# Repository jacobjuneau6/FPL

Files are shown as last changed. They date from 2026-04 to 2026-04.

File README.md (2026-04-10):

# FPL
FPL is a FPGA based board that runs linux and provides many digital interfaces.
# WHY
I have always wanted to have a benchtop device that can probe I2C,SPI and uart devices all ath the same time. In addition, I have always wanted to mess around with and use an FPGA.
# PCB
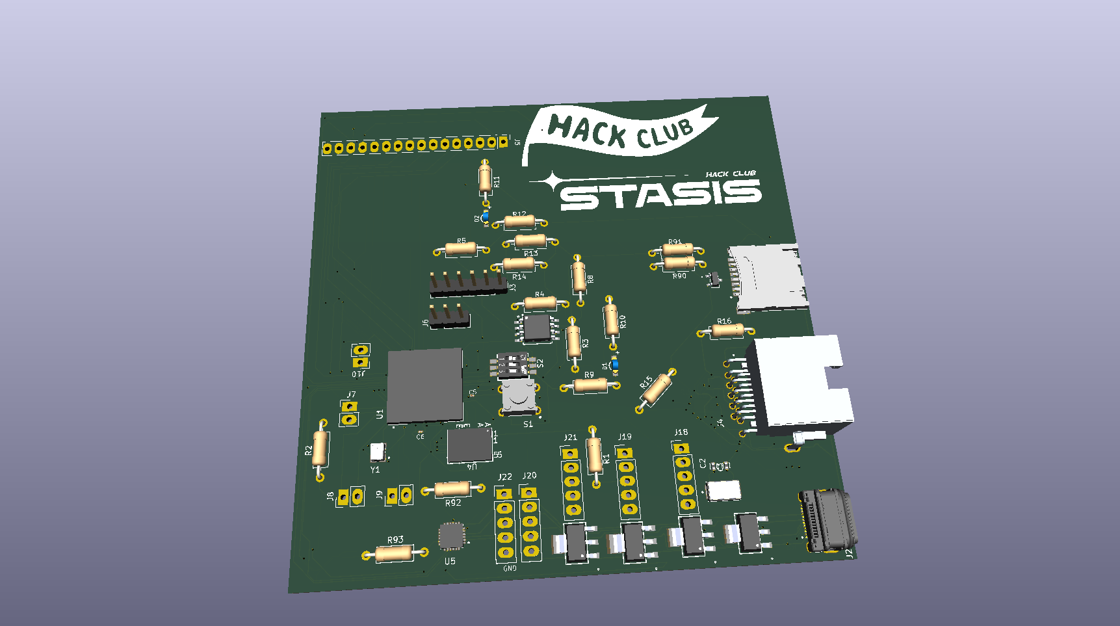
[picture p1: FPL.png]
PCB

# BOM
| Name | Purpose | Quantity | Total Cost (USD) | Link | Distributor |
| --- | --- | --- | --- | --- | --- |
| 50g Solder Paste | To solder the componets to the board | 1 | 7.34 | https://www.aliexpress.com/item/3256809620386958.html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 | Aliexpres |
| FT232H USB -> Bridge | allows programming and debugging the fpga before the core starts | 1 | 7.72 | https://www.aliexpress.com/item/3256810218473690.html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 | Aliexpress |
| M-F Dupont Cable | to connect debugger and peripherals | 1 | 2.27 | https://www.aliexpress.com/item/3256803454873245.html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 | Aliexpress |
| F-F dupont cable | to wire up debugger and peripherals | 1 | 2.06 | https://www.aliexpress.com/item/3256803454873245.html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 | Aliexpress |
| solder paste scraper | to apply the solder paste | 5 | 3.61 | https://www.aliexpress.com/item/3256807243226858.html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 | Aliexpress |
| JLCPCB Stencils | to make assembly easier | 2 | 6.09 |  | JLCPCB |
| JLCPCB PCBs | Holds all components | 5 | 7.00 |  | JLCPCB |
| MicroSD card holder | storage | 1 | 1.57 | https://www.digikey.com/en/products/detail/hirose-electric-co-ltd/DM3CS-SF/2602739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 | Digikey |
| USB-C connector | data transfer | 1 | 2.99 | https://www.digikey.com/en/products/detail/hirose-electric-co-ltd/CX90BW1-24P1/22566049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 | Digikey |
| Ethernet Jack | data transfer | 1 | 4.42 | https://www.digikey.com/en/products/detail/te-connectivity-amp-connectors/2041411-1/7039302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 | Digikey |
| Mosfet | reset the sd card | 1 | 0.28 | https://www.digikey.com/en/products/detail/infineon-technologies/BSS84PH6327XTSA2/5413661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 | Digikey |
| 10K resistors | filtering | 18 | 0.00 |  |  |
| 5.1K resistors | filtering | 2 | 0.20 | https://www.digikey.com/en/products/detail/yageo/RC0402FR-075K1L/726624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 | Digikey |
| Infineon S80KS5123GABHV020 | RAM | 1 | 11.59 | https://www.digikey.com/en/products/detail/infineon-technologies/S80KS5123GABHV020/15965285 | Digikey |
| tactile button | fpga reset | 1 | 0.24 | https://www.digikey.com/en/products/detail/omron-electronics-inc-emc-div/B3F-1000/33150 | Digikey |
| Dip switches | fpga confiuration | 1 | 3.41 | https://www.digikey.com/en/products/detail/w%C3%BCrth-elektronik/416131160803/3174527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 | Digikey |
| FPGA | main chip | 1 | 21.78 | https://www.digikey.com/en/products/detail/lattice-semiconductor-corporation/LFE5U-25F-6BG256C/9553918 | Digikey |
| Ethernet Interface | data transfer | 1 | 1.03 | https://www.digikey.com/en/products/detail/microchip-technology/LAN8720A-CP-TR/3872109 | Digikey |
| 1V2 LDO | power regulation | 1 | 0.39 | https://www.digikey.com/en/products/detail/stmicroelectronics/LD1117S12CTR/1880164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 | Digikey |
| CP2102 | usb>uart | 1 | 4.14 | https://www.digikey.com/en/products/detail/silicon-labs/CP2102N-A02-GQFN24R/9863479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 | Digikey |
| SPI Flash | storage | 1 | 2.31 | https://www.digikey.com/en/products/detail/winbond-electronics/W25Q128JVSIQ-TR/5803944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 | Digikey |
| 25MHZ clock | clock | 1 | 0.99 | https://www.digikey.com/en/products/detail/abracon-llc/ASE-25-000MHZ-L-C-T/1236885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 | Digikey |
| 25MHZ Parrallel clock | ethernet | 1 | 1.02 | https://www.digikey.com/en/products/detail/ecs-inc/ECS-250-18-23A-EN-TR/2213748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 | Digikey |
| 4.7K resistors | filtering | 3 | 0.30 | https://www.digikey.com/en/products/detail/yageo/RC0402JR-074K7L/726477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 | Digikey |
| 0.1uF capacitor | power filtering | 4 | 0.32 | https://www.digikey.com/en/products/detail/murata-electronics/GRM022D80G104ME15L/5027471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 | Digikey |
| 22pF capacitor | power filtering | 2 | 0.16 | https://www.digikey.com/en/products/detail/yageo/CC0402JRNPO9BN220/302752 | Digikey |
| 3V3 LDO | power regulation | 1 | 0.32 | https://www.digikey.com/en/products/detail/stmicroelectronics/LD1117S33CTR/585765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 | Digikey |
| 2V5 LDO | power regulation | 1 | 0.49 | https://www.digikey.com/en/products/detail/stmicroelectronics/LD1117S25CTR/585764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 | Digikey |
| 1V8 LDO | power regulation | 1 | 0.42 | https://www.digikey.com/en/products/detail/stmicroelectronics/LD1117S18TR/1038359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 | Digikey |
| green LED | indication light | 2 | 0.54 | https://www.digikey.com/en/products/detail/w%C3%BCrth-elektronik/155124GS73200A/8557187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 | Digikey |

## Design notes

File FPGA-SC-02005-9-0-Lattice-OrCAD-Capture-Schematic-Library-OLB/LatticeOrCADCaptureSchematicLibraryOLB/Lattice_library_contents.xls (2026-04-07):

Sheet: Revision History
Lattice Semiconductor
Schematic symbol index for OrCAD Capture library: LATTICEPLDS.OLB.
 | Rev No. | Revisions
 |  | 21jul06 1. Added LFXP6-T144, LFXP6-fpBGA256, LFXP20-fpBGA256. 2. Corrected power pins of ECP2-12/22/35/50-fpBGA484.
 |  | 1aug06 Added MachXO_256_csBGA100.
 |  | 9aug06 Added ispMACH4128V/4256V-TQ144
 |  | 31oct06 1. Added LFE2-50-F672 and LFE2M-35-F672. 2. Changed symbol naming conventions to match data sheet conventions.
 |  | 14nov06 Added LCMXO2280-FT324/FTN324
 |  | 10dec06 Added LFE2-6/12/20-F256
 |  | 14dec06 1. Corrected power pins of LFE2-12/22/35/50-F484 2. Added LFE2M-35-F484
 |  | 11jan07 Added LFSC80-FC1704/FCN1704
 |  | 12jan07 Added LFXP15-F484/FN484
 |  | 18jan07 Added LFE2M-20/30-F256
 |  | 24jan07 Added LFE2M-35/50-F672
 |  | 12feb07 1. Added LFE2-6/12-T144/TN144. 2. Added LFE2-12/20-Q208/QN208.
 |  | 23feb07 Added LFXP15/20-F256/FN256.
 |  | 8mar07 Added LFEC2M-70-F900.
 |  | 20mar07 Added LFSC15-F256 and LCMXO256-M100/MN100.
 |  | 21mar07 Added LFE2M-50-F484 and correction to LFSC15-F256.
 |  | 9apr07 Added GAL18V10B.
 |  | 11apr07 Added LFXP6-Q208/QN208.
 |  | 1jun07 1. Added LFXP2-17E-FT256CES. 2. Added LFXP2-17-F484.
 |  | 5jun07 Added LFSC/M25-F900/FN900.
 |  | 15jun07 Added LCMXO2280-T100/TN100
 |  | 12jul07 1. Added LFSCM40-FF1020CES. 2. Added LFXP20-F484/FN484.
 |  | 13jul07 Added LFXP2-17E-Q208/QN208
 |  | 16jul07 Added LFE2-70E-F672/FN672
 |  | 2aug07 Added LFXP2-8E-M132/MN132
 |  | 13aug07 Added LFE2-70E-F900/FN900
 |  | 17sep07 Added ispGAL22V10-J/JN, ispGAL22V10-K/KN
 |  | 19sep07 Added ispGAL22V10A-J, ispGAL22V10A-N
 |  | 26sep07 Added LCMXO640-M132/MN132, LCMXO1200-M132/MN132, LCMXO2280-M132/MN132
 |  | 11oct07 1. Added LFE2-20-F256. 2. LFE2-6/12/20-F256 moved G16 from bank 3 to 2.
 |  | 16oct07 Added LCMXO1200-T144/TN144.
 |  | 23oct07 Added LFXP2-5-M132/MN132.
 |  | 06nov07 1. Updated LFSCM40-FF1020CES to reflect Rev 1.7 of data sheet. 2. Added LFXP2-40E-FPBGA672
 |  | 13nov07 Added LFE2-20E-F672
 |  | 14nov07 Added LFXP2-5E-FT256/FTN256
 |  | 30nov07 Added LC4032Z-M56, LC4064Z-M56
 |  | 13dec07 Added LFE2-35E-F672
 |  | 18dec07 Swapped bank labels 2 and 3. Removed LSCC logo.
 |  | 07jan08 Added LFE2M-70-F1152
 |  | 21jan08 Added LFE2M-100-F1152
 |  | 15feb08 Added LC4384-F256
 |  | 25feb08 1. Corrected PLL FB/IN pins of LFECP6/10/15/20-F484/FN484 2. Added LFE6-F484/FN484 and LFECP6-F484/FN484 based on 3.1 of data sheet
 |  | 12mar08 Moved pin C8 from Bank 1 to Bank 0 LCMXO2280-M132/MN132
 |  | 30Apr08 Added LC4032ZE-TN48, LC4032ZE-MN64, LC4064ZE-TN48, LC4064ZE-MN64, LC4064ZE-TN100, LC4064ZE-MN144, LC4128ZE-TN100, LC4128ZE-MN144, LC4128ZE-TN144, LC4256ZE-TN100, LC4256ZE-MN144, LC4256ZE-TN144 based on April 2008 data sheet
 |  | 12may08 Added LCMXO256-M100/MN100
 |  | 20may08 Updated LFXP2-17E-F484CES using data sheet version 1.4
 |  | 10Jun08 Updated LFXP2-5E-Q208/QN208, LFXP2-8E-Q208/QN208, and LFXP2-8E-F256/FT256.
 |  | 16Jun08 Updated LFXP3-T100/TN100, LFXP3-T144/TN144, LFXP6-T144/TN144, LFXP6-F256/FN256, LFXP10-F256/FN256, LFXP10-F388/FN388, LFXP20-F484/FN484, LCMXO256-T100/TN100
 |  | 10Jul08 Added LFXP2-30E-FT256/FTN256 and LFXP2-40E-F484/FN484
 |  | 8Sep08 Added LFE2M-100E-F900C
 |  | 6Oct08 Added LFE2M-50E-F900
 |  | 20Oct08 1. Added MachXO: LCMXO640-T100/TN100, LCMXO1200-TN100/TN100, LCMXO2280-T144/TN144, and LCMXO2280-FT256/FTN256. 2. Added ispCLOCK: ispPAC-CLK5304S-01T48/TN48, ispPAC-CLK5308S-01T48/TN48, ispPAC-CLK5312S-01T48/TN48, ispPAC-CLK5316S-01T64/TN64, and ispPAC-CLK5320S-01T64/TN64. 3. Added Power Manager: ispPAC-POWR1014-01T48/TN48, ispPAC-POWR1014A-01T48/TN48, ispPAC-POWR1208-01T44/TN44, ispPAC-POWR1208P1-01T44/TN44, ispPAC-POWR1220AT8-01T100/TN100, ispPAC-POWR604-01T44/TN44, ispPAC-POWR604/1208-01T44/TN44, ispPAC-POWR607-01N32/NN32, ispPAC-POWR6AT6-01N32/NN32.
 |  | 23Feb09 1. Added ispPAC-CLK5406D-01-SN48 and ispPAC-CLK5410D-01-SN64
 |  | 30Feb09 1. Added LFE3-70-FN484
 |  | 23Mar09 1. Added LFE3-35-FN484
 |  | 25Mar09 1. Added LFE3-17E-FN256CES, LFE3-17E-FN484CES, LFE3-35E-FN256CES, LFE3-35E-FN672CES, LFE3-70E-FN672CES, LFE3-70E-FN1156CES, LFE3-95E-FN484CES, LFE3-95E-FN672CES, LFE3-95E-FN1156CES, LFE3-150E-FN672CES, LFE3-150E-FN1156CES, LX64-F100C, LX128-F208C, LX256-F484C
 |  | 2010-05-24
 |  | 1. Added LFE-17EA/35EA-FN256
 |  | 2010-06-04
 |  | 1. Deleted LFE-35E-FN256 -- Use EA part instead
 |  | 2010-06-17
 |  | 1. Deleted LFE3-17E-FN256CES -- Use EA part instead
 |  | 2010-07-14
 |  | 1. Corrected GND pins for LC4032ZE-MN64 and LC4064ZE-MN64
 |  | 2010-08-07
 |  | 1. Marked pins AH24,25,26 and 27 as NC for the LFSC15-F900
 |  | 2010-08-07
 |  | 1. Renamed ECP3 35,70 and 95 from E to EA. Same pinouts
 |  | 2011-01-10
 |  | 1. Added LFE3-150EA-FN1156C, this is the symbol used on the ECP3 IO Procotol evaluation board. It has separated bank symbols with indication for DQ groups, DQS, and true LVDS outputs.
 |  | 2011-01-13
 |  | 1. Added MachXO2 LCMX02-1200-TG100 and MG132, LCMXO2-2000-FTG256. 2. Platform Manager LPTM10-1247-TG128 and LPTM10-12107-FTG208.
 |  | 2011-07-12
 |  | 1. LCMXO2-1200-TG100 Changed VCCP pin 89 to NC
 |  | 2. LCMXO2-1200-MG132 Changed VCCP pin C7 to NC
 |  | 3. LCMXO2-1200-TG144 Changed VCCP pin 129 to NC
 |  | 4. LCMXO2-2000-FTG256 Changed VCCP pin A2 to NC
 |  | 2011-07-22
 |  | LFSC15-F900 1) Added missing NC pins
 |  | 2) Consolidated VCC12 pins in one place
 |  | 3) Added secondary functions
 |  | 2011-08-18
 |  | 1. Added MachXO2, LCMXO2-1200-UWG25
 |  | 2. Corrected VCCIO pin type from Bidirectional to Power
 |  | 2011-08-24
 |  | 1. Added MachXO2, LCMXO2-2000/4000/7000-FG484
 |  | 2011-09-08
 |  | Moved pins 50 and 75 on XO2-100 to correspond to actual part
 |  | 2011-09-09
 |  | Corrected duplicate pin numbers on MachXO2, LCMXO2-2000/4000/7000-FG484
 |  | 2011-09-12
 |  | Added MachLCMXO2-2000/4000/7000-TG144
 |  | 2011-11-16
 |  | Corrected mis-numbered NC pin on MachXO2, LCMXO2-2000/4000/7000-FG484
 |  | 2011-12-06
 |  | Added MachLCMXO2-256/640/1200/2000-T100
 |  | 2011-12-13
 |  | Cleaned up LFE3-70EA-FN1156CES
 |  | 2012-02-09
 |  | Added MachLCMXO2-1200/2000/4000/7000-FTG256
 |  | 2012-02-16
 |  | Added LFE3-17EA-MG328
 |  | 2012-02-21
 |  | Corrected missing VCCJ pin on LFE2M-50-484
 |  | 2012-02-22
 |  | Added LCMXO2-256-UMG64
 |  | 2012-04-02
 |  | Added LCMXO2-2000-BG256
 |  | 2012-04-18
 |  | Corrected ECP3 names: E to EA and removed CES designation
 |  | 2012-04-25
 |  | Added LCMXO2-256-SG32
 |  | 2012-05-30
 |  | Added LFXP2-40E/30E-FPGA672C
 |  | 2012-06-05
 |  | Renamed LFE3-95/150EA-FN1156, added notes
 |  | 2012-06-05
 |  | Added LCMXO2-640U-TG144
 |  | 2012-06-12
 |  | Corrected labeling of DQ pins on LCMXO2-640U-TG144
 |  | 2012-08-20
 |  | Added LC4512-F256 and LCMXO2-4000-BG332
 |  | 2012-08-21
 |  | Renamed LFE3-95/150EA-FN1156, at LBN
 |  | 2012-09-03
 |  | LFE3-35EA-FN484; Corrected pin type for VCC,VCCAUX, VCCPLL & VCCA from Passive to Power.
 |  | 2012-09-17
 |  | Added LCMXO2-256/640/1200/2000-TG100,
 |  | Added LCMXO2-256/640/1200/2000/4000-MG132
 |  | Renamed pin names for LCMXO2-1200-UWG25
 |  | 2012-09-21
 |  | Added LCMXO2-2K/4K/7K-BG256,
 |  | Added "7000-BG332" device, and changed the symbol name from "LCMXO2-4000-BG332" to :LCMXO2-4000/7000-BG332"
 |  | 2013-01-28
 |  | Corrected LCMXO2-1200-UWG25
 |  | 2013-02-08
 |  | LFE3-95/150EA-FN1156 added CSSPIN ( dual function pin); LFE3-70/95/150EA-FN1156 moved K8/K9 to bank7. LFE3-35EA-FN484 added secondary functions.
 |  | 12-Feb-13 Added MachXO2-4K-184CsBGA Package
 | rev02.0 | 19-April-2013 Added iCE40 device symbols
 |  | iCE40LP384-CM36A
 |  | iCE40LP384-CM49
 |  | iCE40LP384-CM81
 |  | iCE40LP384-QN32
 |  | iCE40LP1K-CB81
 |  | iCE40LP1K-QN84
 |  | iCE40LP1K-CM81
 |  | iCE40LP1K-CM121
 |  | iCE40LP1K-CM36
 |  | iCE40LP1K-CB121
 |  | iCE40LP1K-CM49
 |  | iCE40LP4K-CM81
 |  | iCE40LP4K-CM121
 |  | iCE40LP4K-CM225
 |  | iCE40LP8K-CM81
 |  | iCE40LP8K-CM121
 |  | iCE40LP8K-CM225
 |  | iCE40HX1K-TQ144
 |  | iCE40HX1K-CB132
 |  | iCE40HX1K-VQ100
 |  | iCE40HX4K-CB132
 |  | iCE40HX4K-TQ144
 |  | iCE40HX8K-CB132
 |  | iCE40HX8K-CM225
 |  | iCE40HX8K-CT256
 | rev02.1 | 09-Aug-13 iCE40-LP1K-CM49 updated VPP_FAST pin
 | rev02.2 | 23-Sept-13 iCE40-LM1K-SWG25 added symbol
 | rev02.3 | 21-Oct-13 iCE40-LM1K-SWG25 updated symbol iCE40-LM2K-SWG25 / CE40-LM4K-SWG25 added symbol iCE40-LM1K-CM36 / iCE40-LM2K-CM36 /iCE40-LM4K-CM36 added symbol iCE40-LM1K-CM49 / iCE40-LM2K-CM49 /iCE40-LM4K-CM49 added symbol
 | rev3.0 | Added Internal Symbols
 | rev3.1 | 14th feb Added XO3 symbols [1]LCMXO3L-2100-UWG49 [2]LCMXO3L-1K/2K/4K/7K-BG256
 | rev3.2 | Removed internal Symbols
 | rev3.3 | Updated LCMXO3L-2100-UWG49 with Dual functions
 | rev3.4 | Addedd LCMXO2-200-UWG49
 | rev3.5 | Added ECP5 symbols
 | rev3.6 | Added ECP5 symbols (csBGA285)
 | rev3.7 | Updated ECP5 symbols
 | rev3.8 | Added LCMXO3L-6900-BG400
 | rev3.9 | Added LCMXO3L-4300-UWG81
 | rev3.10 | Added LCMXO3L-2100/4300/6900-BG324 Renamed LCMXO3L-4300/6900 BG400 Added LCMXO3L- 640/1300 MG121 Added LCMXO3L-6900 MG324 Added LCMXO3L-2100/4300-MG324 Added LCMXO3L- 2100 MG121 Added LCMXO3L-1300/2100-MG256 Added LCMXO3L-1300-UWG36 Added LCMXO3L- 4300 MG121
 | rev4.0 | Added iCE5LP-1K-SWG36 / 2K SWG 36 - / 4K SWG36 Added iCE5LP-1K-UWG20 / 2K UWG20 / 4K UWG20
 | rev4.1 | Updated LFE5UM-85-BG381 Added LASC10-SG48 Added LPTM21
 | rev4.2 | Updated LFE5U-25F-MG285 ; LFE5UM-25F-MG285
 | rev4.3 | Updated LCMXO3L-1300-MG121 Updated LCMXO3L-1300-MG256 Updated LCMXO3L-2100-MG121 Updated LCMXO3L-2100-MG256 Updated LCMXO3L-2100-MG324 Updated LCMXO3L-4300-MG121 Updated LCMXO3L-4300-MG256 Updated LCMXO3L-4300-MG324 Updated LCMXO3L-640-MG121 Updated LCMXO3L-6900-MG256 Updated LCMXO3L-6900-MG324 Updated LPTM21 symbol
 | rev4.4 | Added iCE40UL1K-CM36A and iCEUL-1K SWG16
 | rev4.5 | Added iCE5LP-1K-CM36 and iCE5LP-1K-SG48 Added iCE5LP-2K-CM36 and iCE5LP-2K-SG48 Added iCE5LP-4K-CM36 and iCE5LP-4K-SG48
 | rev4.6 | Updated LFE5U-25F-MG285
 | rev4.7 | Added iCE40UP5K-WLCSP30 & iCE40UP5K- SG48
 | rev4.8 | Updated LCMXO3L-1300-UWG36
 | rev4.9 | Added LFE5G-25F-BG381 LFE5G-25F-MG285 LFE5G-45F-BG381 LFE5G-45F-BG554 LFE5G-45F-MG285 LFE5G-85F-BG381 LFE5G-85F-BG554 LFE5G-85F-BG756 LFE5G-85F-MG285
 | rev4.10 | Added LIF-MD6000 CSFBGA81 LIF-MD6000 WLCSP36
 | rev5.1 | Added iCE40UP3K-WLCSP30 & iCE40UP5K- FWG49
 | rev5.2 | Updated Ice40up5k-WLCSP30 (Swapped C1 & D1) Added LIFMD6000-CSFBGA64 & LIFMD6000-CSFBGA80
 | rev5.3 | Updated LFE5UM-25F-MG285 BANK3 Pin Numbers
 | rev5.3 | Updated LFE5UM/5G-85F-MG285 SERDES Pin Numbers Grouped LIFMD6000-Ctfbga80
 | rev5.4 | Updated ice40up3k/5k RGB Pin swaps. Added SII1866CZU
 | rev5.5 | Updated ice40up3k-WLCSP30(Swapped C1 & D1)
 | rev5.6 | Updated LIFMD6000-CSFBGA64. Swapped H3&H4, G7&G8, A6&B6
 | rev5.7 | Added -LCMXO2-256/1200-SG32 -LCMXO2-4000-QFN84 -LCMXO2-256/640-QFN48 -LCMXO3L/LF -9400-MG256 -LCMXO3L/LF-9400-BG256 -LCMXO3L/LF-9400-BG400 -LCMXO3L/LF-9400-BG484
 | rev5.8 | Added LCMXO3H-40E-6FN672I
 | rev5.9 | Removed internal names on all the ECP5 Symbols
 | rev6.0 | Updated All LIFMD Package VCCAUX Pin name and Modifed 80 Pin package VSS to GND. Updated C4 & D5 Swap on 64 Pin package.
 | rev6.1 | Nov-2018 Added -LFE5U-12F-BG256 -LFE5U-25F-BG256 Corrected Ultra Family symbols, changed pin "*SPI_CSN" to "*SPI_SS"
 | rev6.3 | Feb-2019 Broke old LCMXO3L-2100/4300/6900-BG324 symbol into 2 parts: - LCMXO3L-2100/4300-BG324 (no changes) - LCMXO3L-6900-BG324 (updated pin names, no change to pin numbers)
 | rev6.4 | Sept-2019 Added -LFE5UM-45F-BG256 -LIFMDF6000-ucFBGA64
 | rev6.5 | March 2020 - added LPTM21L-CAG100
 | rev6.6 | April 2020 Added -LIFCL-40-BG400 -LIFCL-40-MG289 -LIFCL-40-SG72
 | rev6.7 | June 2020 Added -LIFCL-40-MG121 -LIFCL-40-BG256 -LFD2NX-40-BG256 -Pin updates on LIFCL-40-BG400: Minor name update on ball D15, fixed ball swap error on R16/T16 -Pin update on LIFCL-40-SG72: Minor name update on pin 53
 | rev6.8 | July 2020 -Pin update on LIFCL-40-400: Fixed swapped pin error on PT84A and PT84B
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

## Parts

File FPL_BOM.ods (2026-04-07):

Name | Purpose | Quantity | Total Cost (USD) | Link | Distributor
0.1uF capacitor | power smoothing | 23 | 0.07 | https://www.digikey.com/en/products/detail/murata-electronics/GRM022D80G104ME15L/5027471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 | Digikey
3.3V LDO | Power regulation | 1 | 0.32 | https://www.digikey.com/en/products/detail/stmicroelectronics/LD1117S33CTR/585765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 | Digikey
2.5V LDO | Power regulation | 1 | 0.49 | https://www.digikey.com/en/products/detail/stmicroelectronics/LD1117S25CTR/585764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 | Digikey
Green LED | Indicator Light | 2 | 0.54 | https://www.digikey.com/en/products/detail/w%C3%BCrth-elektronik/155124GS73200A/8557187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 | Digikey
Lattice ECP5 FPGA | Main MCU | 1 | 19.55 | https://www.mouser.com/ProductDetail/Lattice/LFE5U-25F-6TG144C?qs=TuK3vfAjtkUJ2XBiIF%2F%2FCA%3D%3D | Mouser
MicroSD card Slot | Hold a MicroSD card for data | 1 | 1.57 | https://www.digikey.com/en/products/detail/hirose-electric-co-ltd/DM3CS-SF/2602739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 | Digikey
USB-C connector | Provides power and data | 1 | 2.99 | https://www.digikey.com/en/products/detail/hirose-electric-co-ltd/CX90BW1-24P1/22566049 | Digikey
P-Channel Mosfet | Resets MicroSD card | 1 | 0.28 | https://www.digikey.com/en/products/detail/infineon-technologies/BSS84PH6327XTSA2/5413661 | Digikey
10K resistors | Voltage smoothing | 9 | 0
5.1K resistors | Voltage smoothing | 2 | 0.2 | https://www.digikey.com/en/products/detail/yageo/RC0402FR-075K1L/726624 | Digikey
4.7K resistors | Voltage smoothing | 4 | 0.4 | https://www.digikey.com/en/products/detail/yageo/RC0402JR-074K7L/726477 | Digikey
47 OHM resistors | Logic Filtering | 78 | 4.06 | https://www.digikey.com/en/products/detail/rohm-semiconductor/KTR10EZPJ470/1763409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 | Digikey
Tactile Switch | Reset Button | 1 | 0.24 | https://www.digikey.com/en/products/detail/omron-electronics-inc-emc-div/B3F-1000/33150 | Digikey
3 Position DIP switch | FPGA State Control | 1 | 3.41 | https://www.digikey.com/en/products/detail/w%C3%BCrth-elektronik/416131160803/3174527 | Digikey
32MB SDRAM | RAM for RISCV CPU core | 2 | 10.38 | https://www.digikey.com/en/products/detail/winbond-electronics/W9825G6KH-6/5001919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 | Digikey
1.2V LDO | Power regulation | 1 | 0.39 | https://www.digikey.com/en/products/detail/stmicroelectronics/LD1117S12CTR/1880164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 | Digikey
16MB SPI flash | FPGA STATE data and RISC-V microcode | 1 | 2.31 | https://www.digikey.com/en/products/detail/winbond-electronics/W25Q128JVSIQ-TR/5803944 | Digikey
CP2102 USB>UART | provides uart over usb from FPGA | 1 | 4.14 | https://www.digikey.com/en/products/detail/silicon-labs/CP2102N-A02-GQFN24R/9863479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 | Digikey
25MHZ clock | provides a base clock for the FPGA | 1 | 0.99 | https://www.digikey.com/en/products/detail/abracon-llc/ASE-25-000MHZ-L-C-T/1236885 | Digikey

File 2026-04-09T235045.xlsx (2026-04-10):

Digi-Key: Shopping Cart
Index | Quantity | Part Number | Manufacturer Part Number | Description | Customer Reference | Available | Backorder | Unit Price | Extended Price USD
1 | 1 | BSS84PH6327XTSA2CT-ND | BSS84PH6327XTSA2 | MOSFET P-CH 60V 170MA SOT23-3 |  | 1 | 0 | 0.26 | 0.26
2 | 1 | A135635CT-ND | 2041411-1 | RJ45 W/ LED, TAB UP, OFFSET, DIP |  | 1 | 0 | 4.42 | 4.42
3 | 1 | 26-CX90BW1-24P1CT-ND | CX90BW1-24P1 | RECEPTACLE, 24POS., USB TYPE-C C |  | 1 | 0 | 2.99 | 2.99
4 | 1 | HR1972CT-ND | DM3CS-SF | CONN MICRO SD CARD R/A SMD |  | 1 | 0 | 1.57 | 1.57
5 | 2 | 311-5.10KLRCT-ND | RC0402FR-075K1L | RES 5.1K OHM 1% 1/16W 0402 |  | 2 | 0 | 0.1 | 0.20
6 | 1 | 448-S80KS5123GABHV020-ND | S80KS5123GABHV020 | IC PSRAM 512MBIT SPI/OCTL 24FBGA |  | 1 | 0 | 11.59 | 11.59
7 | 1 | SW400-ND | B3F-1000 | SWITCH TACTILE SPST-NO 0.05A 24V |  | 1 | 0 | 0.24 | 0.24
8 | 1 | 732-416131160803CT-ND | 416131160803 | SWITCH SLIDE DIP SPST 0.025A 24V |  | 1 | 0 | 3.41 | 3.41
9 | 1 | 220-2205-ND | LFE5U-25F-6BG256C | IC FPGA 197 I/O 256CABGA |  | 1 | 0 | 21.78 | 21.78
10 | 1 | LAN8720A-CP-CT-ND | LAN8720A-CP-TR | IC TRANSCEIVER FULL 2/2 24QFN |  | 1 | 0 | 1.03 | 1.03
11 | 1 | 497-6974-1-ND | LD1117S12CTR | IC REG LINEAR 1.2V 800MA SOT-223 |  | 1 | 0 | 0.39 | 0.39
12 | 1 | 336-5888-1-ND | CP2102N-A02-GQFN24R | IC USB TO UART BRIDGE QFN24 |  | 1 | 0 | 4.14 | 4.14
13 | 1 | W25Q128JVSIQ-ND | W25Q128JVSIQ | IC FLASH 128MBIT SPI/QUAD 8SOIC |  | 1 | 0 | 2.24 | 2.24
14 | 1 | 535-ASE-25.000MHZ-L-C-TCT-ND | ASE-25.000MHZ-L-C-T | XTAL OSC XO 25.0000MHZ CMOS SMD |  | 1 | 0 | 0.99 | 0.99
15 | 1 | XC1671CT-ND | ECS-250-18-23A-EN-TR | CRYSTAL 25.0000MHZ 18PF SMD |  | 1 | 0 | 1.02 | 1.02
16 | 3 | 311-4.7KJRCT-ND | RC0402JR-074K7L | RES 4.7K OHM 5% 1/16W 0402 |  | 3 | 0 | 0.1 | 0.30
17 | 1 | 497-1241-1-ND | LD1117S33CTR | IC REG LINEAR 3.3V 800MA SOT-223 |  | 1 | 0 | 0.32 | 0.32
18 | 10 | 311-1018-1-ND | CC0402JRNPO9BN220 | CAP CER 22PF 50V C0G/NPO 0402 |  | 10 | 0 | 0.003 | 0.03
19 | 1 | 497-1240-1-ND | LD1117S25CTR | IC REG LINEAR 2.5V 800MA SOT-223 |  | 1 | 0 | 0.49 | 0.49
20 | 1 | 497-7308-1-ND | LD1117S18TR | IC REG LINEAR 1.8V 800MA SOT-223 |  | 1 | 0 | 0.42 | 0.42
21 | 2 | 732-12022-1-ND | 155124GS73200A | LED GREEN CLEAR 1206 SMD R/A |  | 2 | 0 | 0.27 | 0.54

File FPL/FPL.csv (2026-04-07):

Reference | Qty | Value | DigiKey_Part_Number | Mouser Part Number
C1,C4,C5,C6 | 4 | GRM022D80G104ME15L | 490-10386-1-ND
C2,C3 | 2 | CC0402JRNPO9BN220 | 311-1018-1-ND
CR1 | 1 | LD1117S33CTR | LD1117S33CTR
CR2 | 1 | LD1117S25CTR | LD1117S25CTR
CR3 | 1 | LD1117S18TR
D1,D2 | 2 | WL-SMSW_1204_A | 732-12022-1-ND
J1 | 1 | DM3CS-SF | HR1972CT-ND
J2 | 1 | CX90BW1-24P1 | 26-CX90BW1-24P1CT-ND
J3 | 1 | PINHD_1x6_Male
J4 | 1 | 2041411-1 | A135635CT-ND
J5,J6 | 2 | PINHD_1x16_Male
J7,J8,J9,J10,J11,J12,J13,J14,J15,J16,J17 | 11 | PINHD_1x2_Male
J18,J19,J20,J21,J22 | 5 | PINHD_1x5_Male
Q1 | 1 | BSS84PH6327XTSA2 | BSS84PH6327XTSA2CT-ND
R1,R2,R3,R4,R5,R8,R9,R10,R11,R12,R13,R14,R15,R16,R90,R91,R92,R93 | 18 | 10k | N/A
R6,R7 | 2 | RC0402FR-075K1L | 311-5.10KLRCT-ND
R87,R88,R89 | 3 | RC0402JR-074K7L | 311-4.7KJRCT-ND
S1 | 1 | B3F-1000 | SW400-ND
S2 | 1 | 416131160803 | 732-416131160803CT-ND
U1 | 1 | LFE5U-25F-6BG256C | 220-2205-ND
U2 | 1 | LAN8720A-CP-TR
U3 | 1 | LD1117S12CTR | LD1117S12CTR
U5 | 1 | CP2102N-A02-GQFN24R | 336-5888-1-ND
U6 | 1 | W959D6NFKX4I
U7 | 1 | W25Q128JVSIQ TR | 256-W25Q128JVSIQTRCT-ND
Y1 | 1 | ASE-25.000MHZ-LC-T | 535-ASE-25.000MHZ-L-C-TCT-ND
Y2 | 1 | ECS-250-18-23A-EN-TR | XC1671CT-ND

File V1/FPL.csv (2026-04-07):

Reference | Qty | Value | DigiKey_Part_Number | Mouser Part Number
C1,C2,C3,C4,C5,C6,C7,C8,C9,C10,C11,C12,C13,C14,C15,C16,C17,C18,C19,C20,C21,C22,C23 | 23 | GRM022D80G104ME15L | 490-10386-1-ND
CR1 | 1 | LD1117S33CTR | LD1117S33CTR
CR2 | 1 | LD1117S25CTR | LD1117S25CTR
D1,D2 | 2 | WL-SMSW_1204_A | 732-12022-1-ND
IC1 | 1 | LFE5U-25F-6TG144C |  | 842-LFE5U25F6TG144C
J1 | 1 | DM3CS-SF | HR1972CT-ND
J2 | 1 | CX90BW1-24P1 | 26-CX90BW1-24P1CT-ND
Q1 | 1 | BSS84PH6327XTSA2 | BSS84PH6327XTSA2CT-ND
R1,R2,R3,R4,R5,R90,R91,R92,R93 | 9 | 10k | N/A
R6,R7 | 2 | RC0402FR-075K1L | 311-5.10KLRCT-ND
R8,R87,R88,R89 | 4 | RC0402JR-074K7L | 311-4.7KJRCT-ND
R9,R10,R11,R12,R13,R14,R15,R16,R17,R18,R19,R20,R21,R22,R23,R24,R25,R26,R27,R28,R29,R30,R31,R32,R33,R34,R35,R36,R37,R38,R39,R40,R41,R42,R43,R44,R45,R46,R47,R48,R49,R50,R51,R52,R53,R54,R55,R56,R57,R58,R59,R60,R61,R62,R63,R64,R65,R66,R67,R68,R69,R70,R71,R72,R73,R74,R75,R76,R77,R78,R79,R80,R81,R82,R83,R84,R85,R86 | 78 | KTR10EZPJ470 | RHM47BCT-ND
S1 | 1 | B3F-1000 | SW400-ND
S2 | 1 | 416131160803 | 732-416131160803CT-ND
U1,U2 | 2 | W9825G6KH-6 | W9825G6KH-6-ND
U3 | 1 | LD1117S12CTR | LD1117S12CTR
U4 | 1 | W25Q128JVSIQ TR | 256-W25Q128JVSIQTRCT-ND
U5 | 1 | CP2102N-A02-GQFN24R | 336-5888-1-ND
Y1 | 1 | ASE-25.000MHZ-LC-T | 535-ASE-25.000MHZ-L-C-TCT-ND

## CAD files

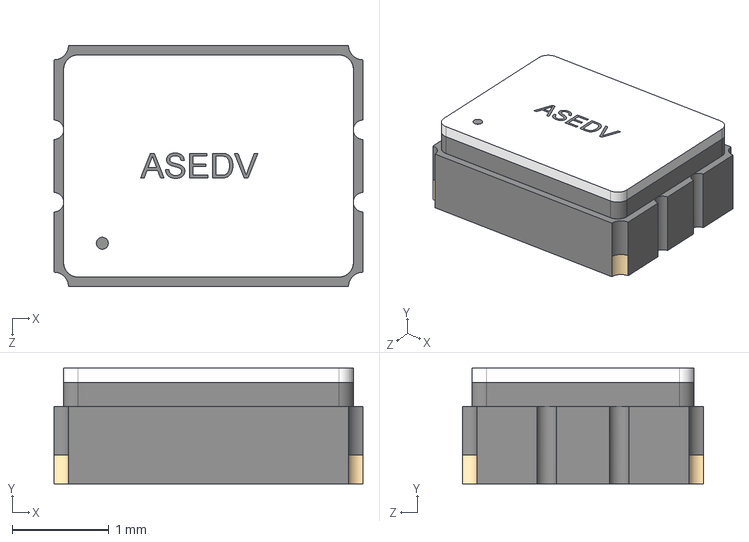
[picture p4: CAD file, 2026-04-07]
FPL/symbols/ASE-25.000MHZ-LC-T/ASE-25.000MHZ-LC-T.step
3.20 x 1.20 x 2.50 mm

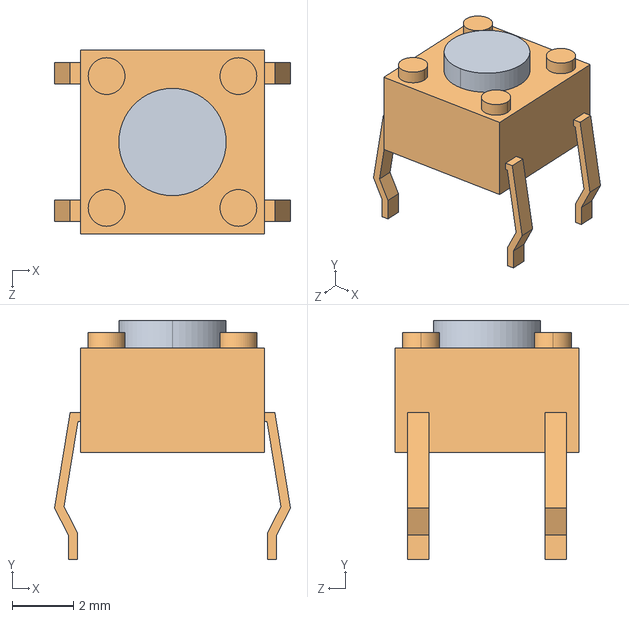
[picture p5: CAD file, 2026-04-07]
FPL/symbols/B3F-1000/B3F-1000.step
7.70 x 7.80 x 6.00 mm
B3F_1000_BUTTON
B3F_1000_BASE

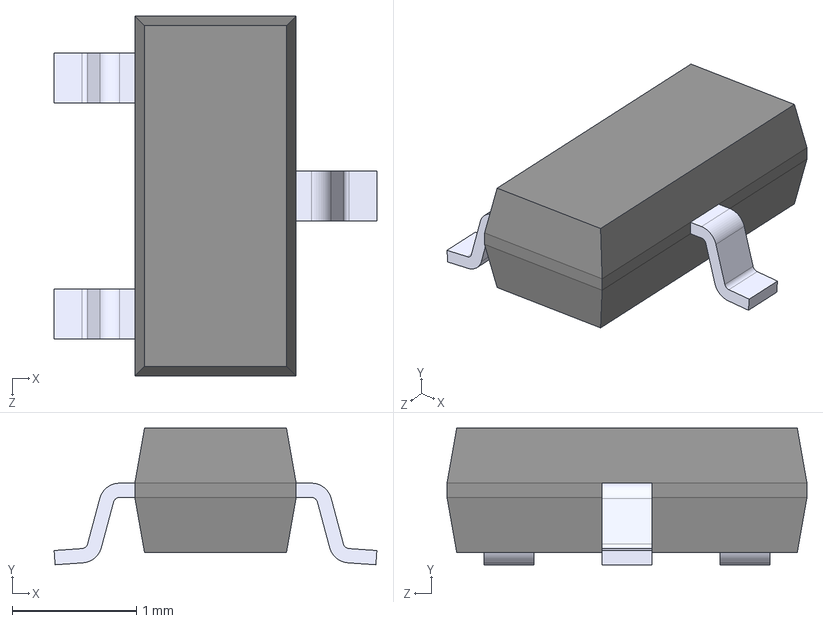
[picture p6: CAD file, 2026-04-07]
FPL/symbols/BSS84PH6327XTSA2.STEP
2.60 x 1.10 x 2.90 mm

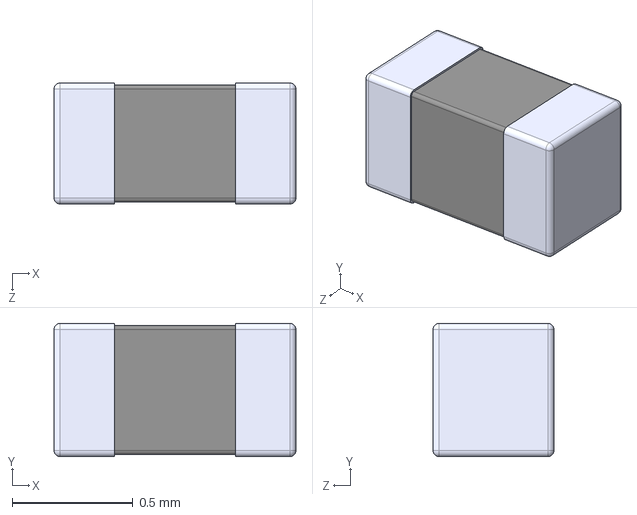
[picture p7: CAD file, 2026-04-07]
FPL/symbols/CC0402JRNPO9BN220/CC0402JRNPO9BN220.step
1.00 x 0.55 x 0.5 mm

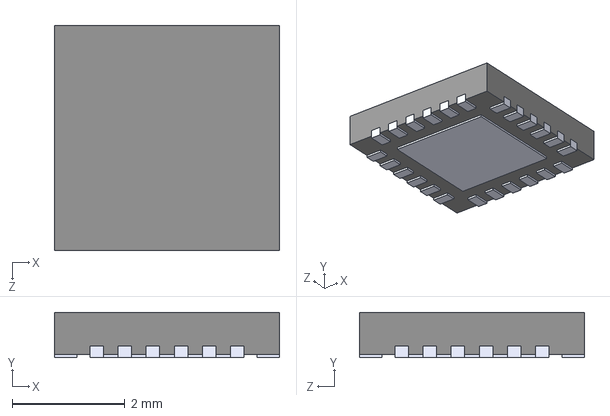
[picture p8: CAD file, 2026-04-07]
FPL/symbols/CP2102N-A02-GQFN24R/CP2102N-A02-GQFN24R.step
4.00 x 0.8 x 4.00 mm

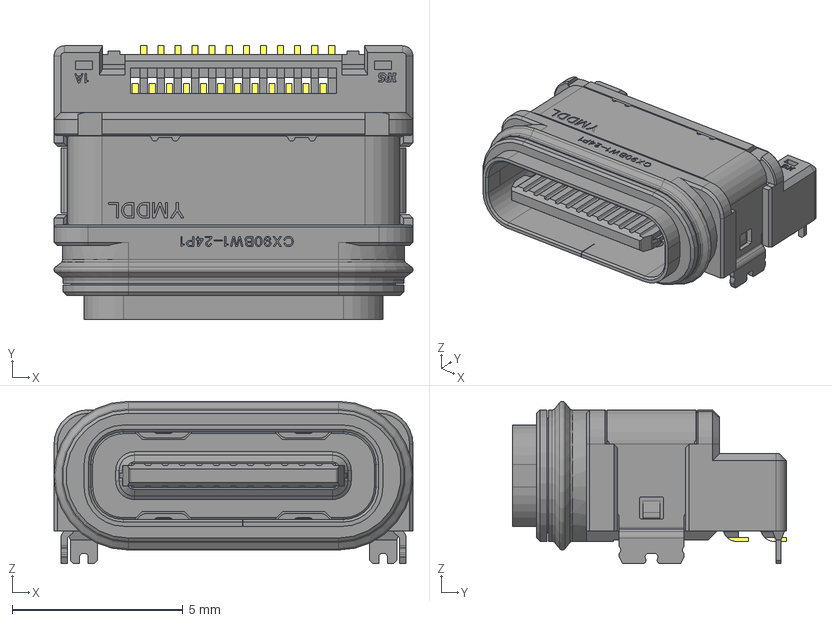
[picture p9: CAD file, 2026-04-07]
FPL/symbols/CX90BW1-24P1/CX90BW1-24P1.step
10.5 x 8.00 x 4.75 mm

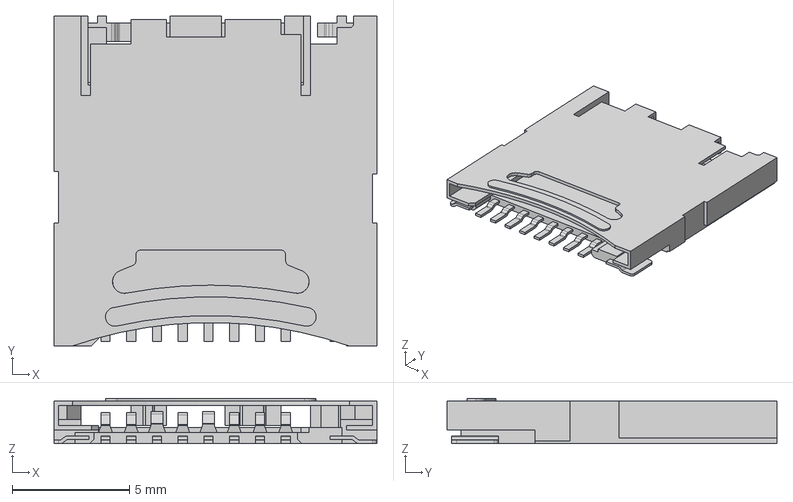
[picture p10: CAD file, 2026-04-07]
FPL/symbols/DM3CS-SF/DM3CS-SF.step
13.8 x 14.1 x 1.93 mm

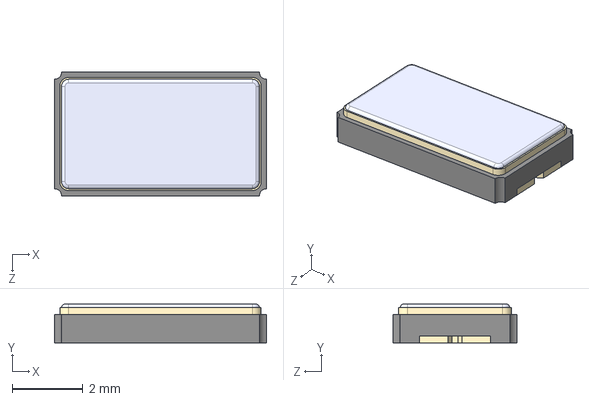
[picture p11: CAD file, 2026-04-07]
FPL/symbols/ECS-250-18-23A-EN-TR/ECS-250-18-23A-EN-TR.step
6.00 x 1.10 x 3.50 mm

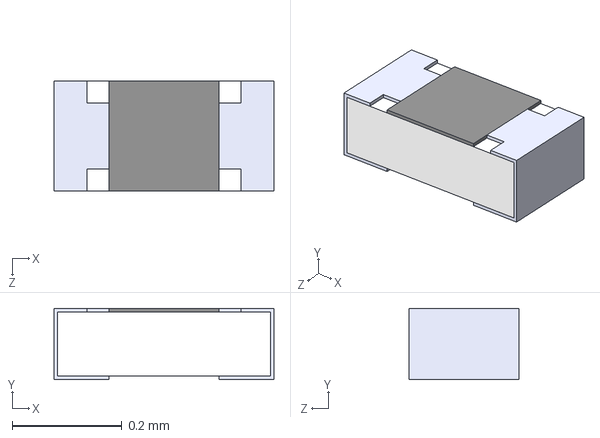
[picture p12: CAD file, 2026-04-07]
FPL/symbols/ERJXGNF47R0Y/ERJXGNF47R0Y.step
0.4 x 0.13 x 0.2 mm

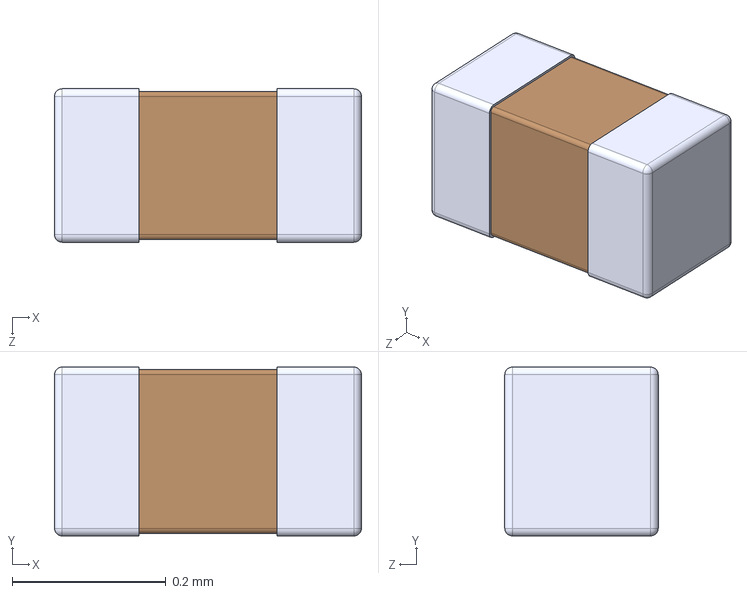
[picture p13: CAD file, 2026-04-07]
FPL/symbols/GRM022D80G104ME15L/GRM022D80G104ME15L.step
0.4 x 0.22 x 0.2 mm

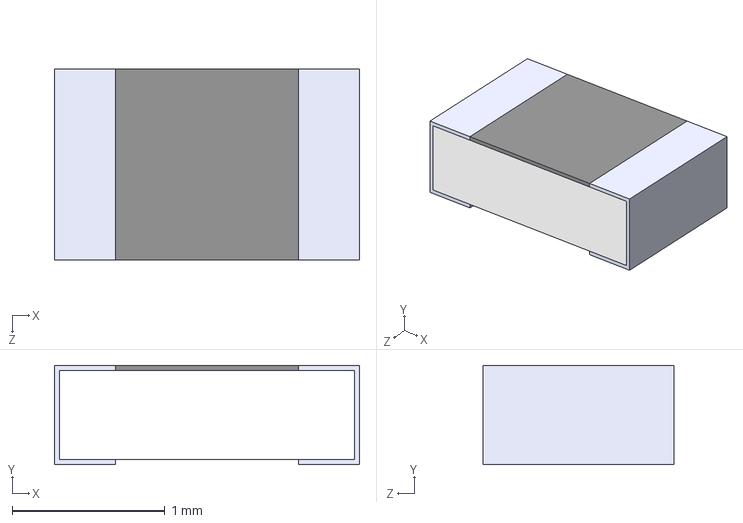
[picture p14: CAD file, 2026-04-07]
FPL/symbols/KTR10EZPJ470/KTR10EZPJ470.step
2.00 x 0.65 x 1.25 mm

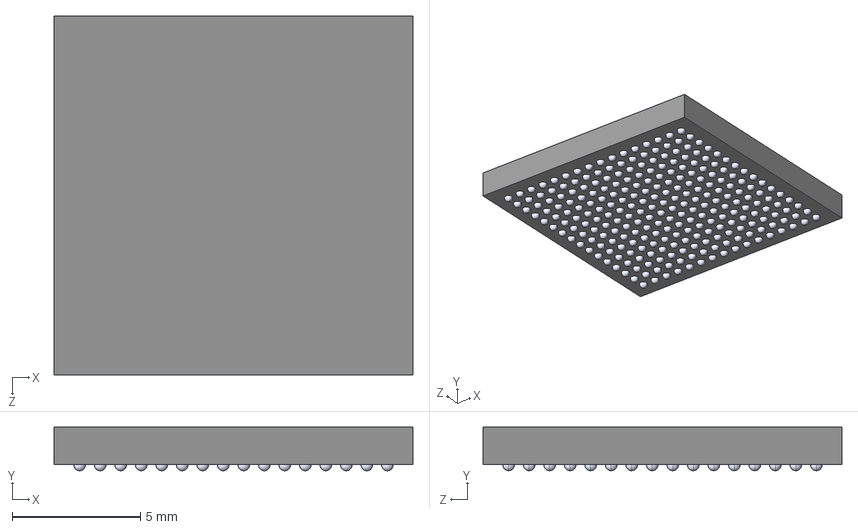
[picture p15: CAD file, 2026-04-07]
FPL/symbols/LFE5U-25F-6BG256C/LFE5U-25F-6BG256C.step
14.0 x 1.70 x 14.0 mm

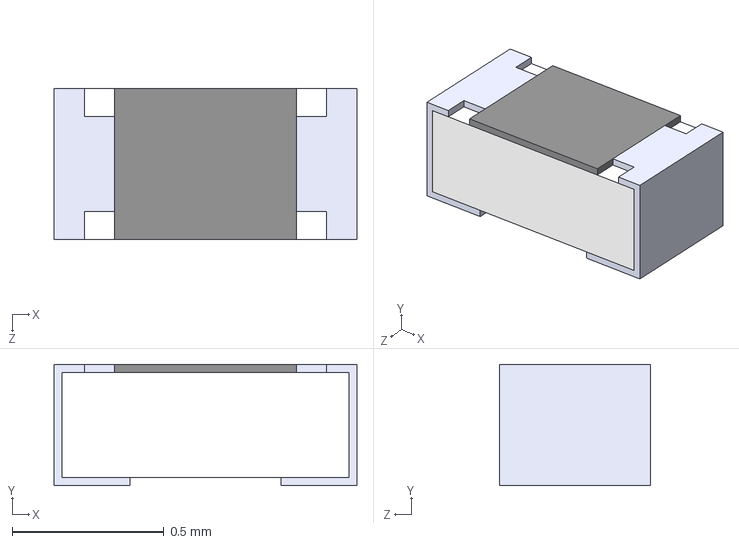
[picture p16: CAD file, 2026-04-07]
FPL/symbols/RC0402JR-074K7L/RC0402JR-074K7L.step
1.00 x 0.4 x 0.5 mm

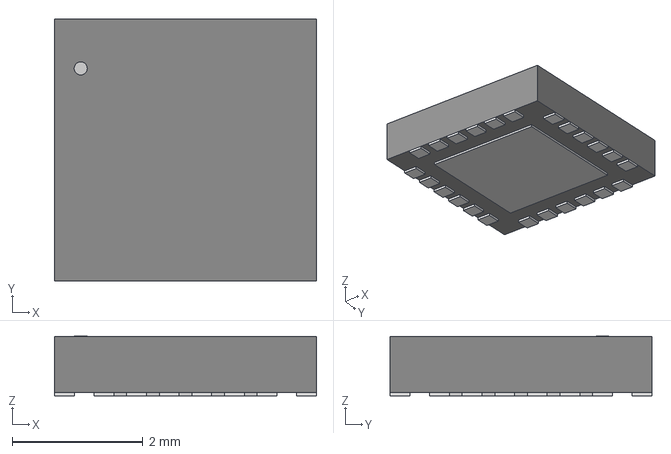
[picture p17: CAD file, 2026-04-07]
FPL/symbols/ul_LAN8720A-CP-TR-3/QFN24-6X6_MC_MCH.step
4.01 x 4.01 x 0.917 mm

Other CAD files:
FPL/symbols/ul_S80KS5123GABHV020-3/PG-BGA-24-801.step
FPL/symbols/W9825G6KH-6/W9825G6KH-6.step
FPL/symbols/WL-SMSW_1204_A/WL-SMSW_1204_A.step
FPL/symbols/2041411-1/2041411-1.step
FPL/symbols/416131160803/416131160803.step
FPL/symbols/LD1117S33CTR--3DModel-STEP-418109.STEP
FPL/symbols/LIB_LFE5U-25F-6TG144C/LFE5U-25F-6TG144C/Allegro/qfp50p2200x2200x160-144n.psm
FPL/symbols/LIB_LFE5U-25F-6TG144C/LFE5U-25F-6TG144C/DEHDL/lfe5u_25f_6tg144c/chips/chips.prt
FPL/symbols/W25Q128JVSIQ TR.STEP
V1/symbols/416131160803/416131160803.step
V1/symbols/LIB_LFE5U-25F-6TG144C/LFE5U-25F-6TG144C/Allegro/qfp50p2200x2200x160-144n.psm
V1/symbols/LIB_LFE5U-25F-6TG144C/LFE5U-25F-6TG144C/DEHDL/lfe5u_25f_6tg144c/chips/chips.prt
V1/symbols/W9825G6KH-6/W9825G6KH-6.step
V1/symbols/WL-SMSW_1204_A/WL-SMSW_1204_A.step

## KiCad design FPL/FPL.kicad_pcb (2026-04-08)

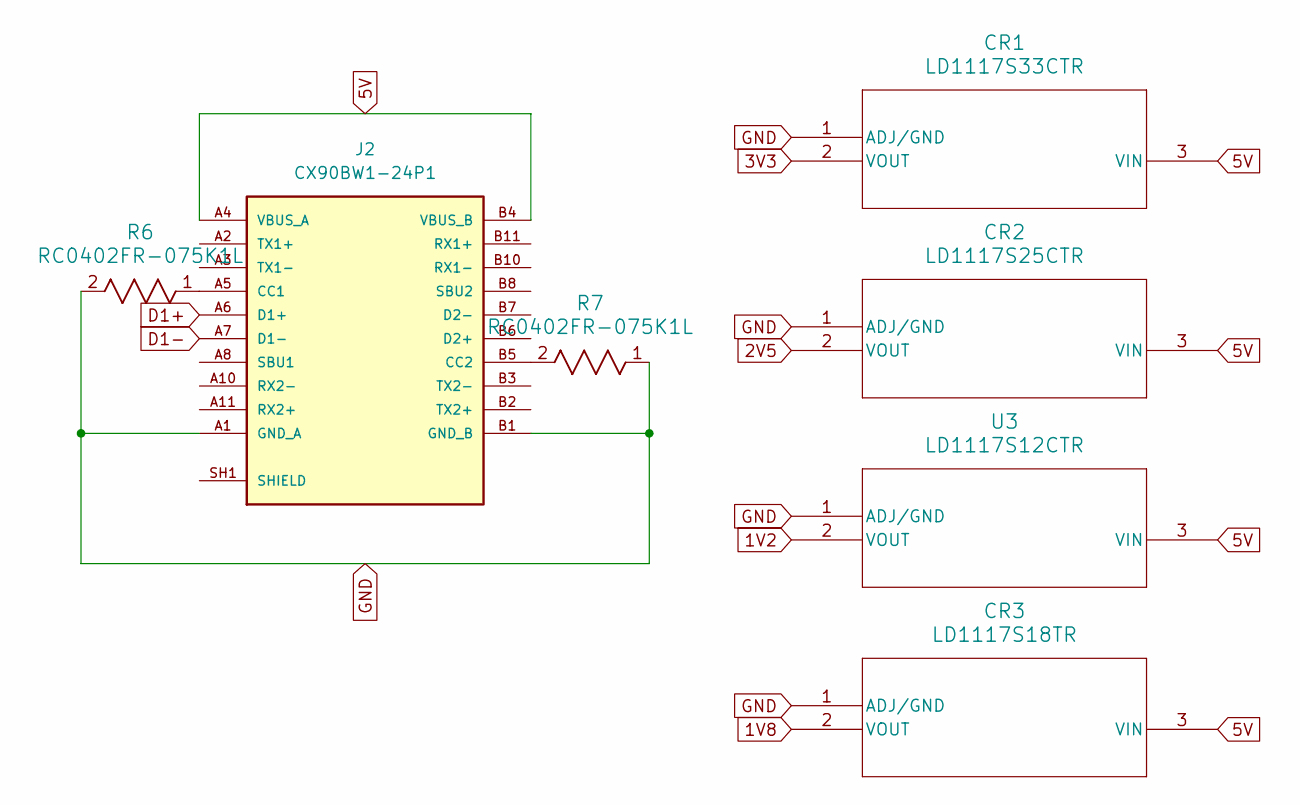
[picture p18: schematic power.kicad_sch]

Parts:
CR1: LD1117S33CTR; SOT-223_STM; DigiKey_Part_Number LD1117S33CTR
CR2: LD1117S25CTR; SOT-223_STM; DigiKey_Part_Number LD1117S25CTR
CR3: LD1117S18TR; SOT-223_STM-M
J2: CX90BW1-24P1; HIROSE_CX90BW1-24P1; PARTREV 24.05.01; DigiKey_Part_Number 26-CX90BW1-24P1CT-ND
R6, R7: RC0402FR-075K1L; RC0402N_YAG; DigiKey_Part_Number 311-5.10KLRCT-ND
U3: LD1117S12CTR; SOT-223_STM; DigiKey_Part_Number LD1117S12CTR

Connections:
1V2: U3.2 (VOUT); also elsewhere on the board
1V8: CR3.2 (VOUT); also elsewhere on the board
2V5: CR2.2 (VOUT); also elsewhere on the board
3V3: CR1.2 (VOUT); also elsewhere on the board
5V: CR1.3 (VIN), CR2.3 (VIN), CR3.3 (VIN), J2.A4 (VBUS_A), J2.A9 (VBUS_A), J2.B4 (VBUS_B), J2.B9 (VBUS_B), U3.3 (VIN); also elsewhere on the board
D1+: J2.A6 (D1+); also elsewhere on the board
D1-: J2.A7 (D1-); also elsewhere on the board
GND: CR1.1 (ADJ/GND), CR2.1 (ADJ/GND), CR3.1 (ADJ/GND), J2.A1 (GND_A), J2.A12 (GND_A), J2.B1 (GND_B), J2.B12 (GND_B), R6.2, R7.1, U3.1 (ADJ/GND); also elsewhere on the board
unnamed: J2.A5 (CC1), R6.1
unnamed: J2.B5 (CC2), R7.2
unnamed: J2.SH1 (SHIELD), J2.SH2 (SHIELD), J2.SH3 (SHIELD), J2.SH4 (SHIELD)

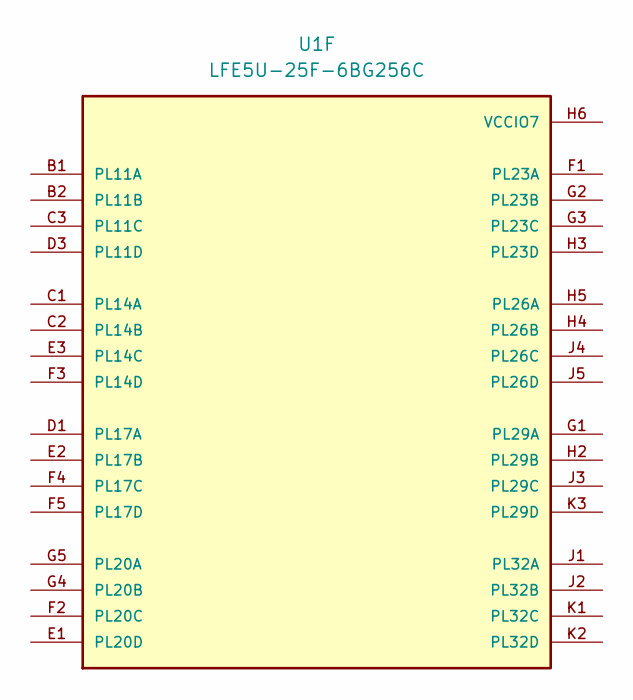
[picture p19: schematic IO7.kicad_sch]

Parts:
U1: LFE5U-25F-6BG256C; BGA256C80P16X16_1400X1400X170; PARTREV 2.8; DigiKey_Part_Number 220-2205-ND

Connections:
VCCIO7: U1.H6 (VCCIO7), U1.H7 (VCCIO7)

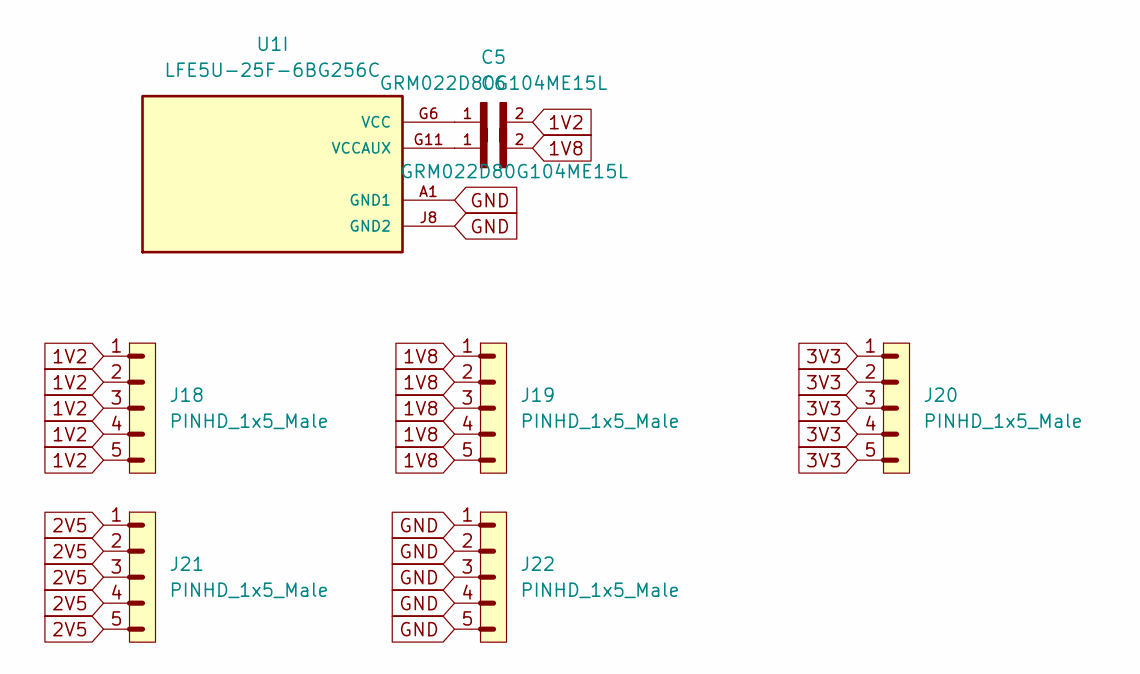
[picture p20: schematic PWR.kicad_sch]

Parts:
C5, C6: GRM022D80G104ME15L; CAPC0402X22N; DigiKey_Part_Number 490-10386-1-ND
J18, J19, J20, J21, J22: PINHD_1x5_Male; PinHeader_1x05_P2.54mm_Vertical
U1: LFE5U-25F-6BG256C; BGA256C80P16X16_1400X1400X170; PARTREV 2.8; DigiKey_Part_Number 220-2205-ND

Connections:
1V2: C5.2, J18.1, J18.2, J18.3, J18.4, J18.5; also elsewhere on the board
1V8: C6.2, J19.1, J19.2, J19.3, J19.4, J19.5; also elsewhere on the board
2V5: J21.1, J21.2, J21.3, J21.4, J21.5; also elsewhere on the board
3V3: J20.1, J20.2, J20.3, J20.4, J20.5; also elsewhere on the board
GND: J22.1, J22.2, J22.3, J22.4, J22.5, U1.A1 (GND1), U1.A16 (GND1), U1.D2 (GND1), U1.D15 (GND1), U1.F8 (GND1), U1.F9 (GND1), U1.G8 (GND1), U1.G10 (GND1), U1.H1 (GND1), U1.H8 (GND1), U1.H9 (GND1), U1.H10 (GND1), U1.H16 (GND1), U1.J8 (GND2), U1.J9 (GND2), U1.J10 (GND2), U1.K6 (GND2), U1.K7 (GND2), U1.K8 (GND2), U1.K9 (GND2), U1.K10 (GND2), U1.N2 (GND2), U1.N15 (GND2), U1.T1 (GND2), U1.T5 (GND2), U1.T12 (GND2), U1.T16 (GND2); also elsewhere on the board
VCC: C5.1, U1.G6 (VCC), U1.G7 (VCC), U1.G9 (VCC), U1.L8 (VCC), U1.L9 (VCC), U1.L10 (VCC)
VCCAUX: C6.1, U1.G11 (VCCAUX), U1.L7 (VCCAUX)

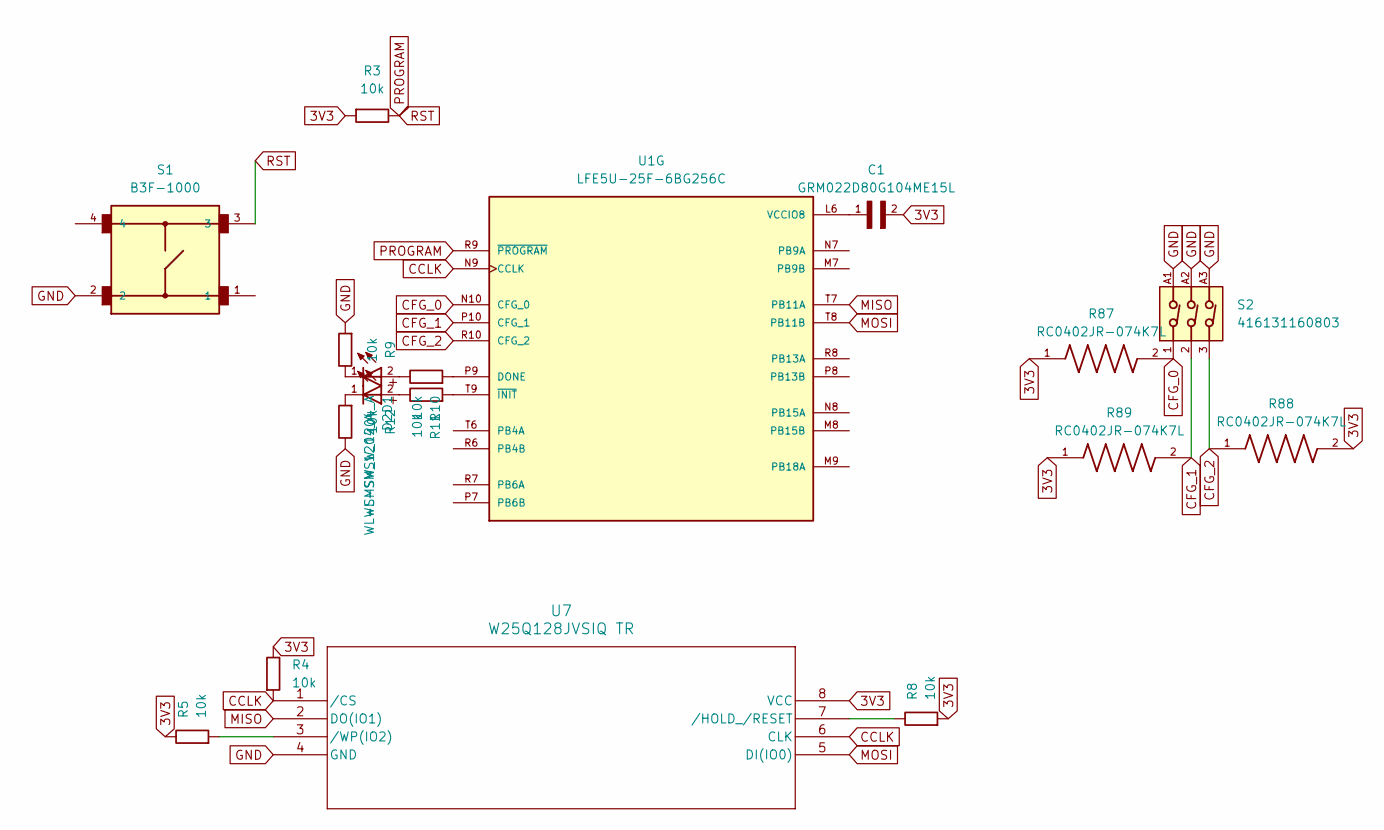
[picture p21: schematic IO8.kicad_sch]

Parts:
C1: GRM022D80G104ME15L; CAPC0402X22N; DigiKey_Part_Number 490-10386-1-ND
D1, D2: WL-SMSW_1204_A; DigiKey_Part_Number 732-12022-1-ND
R3, R9, R10, R11, R12: 10k; R_Axial_DIN0207_L6.3mm_D2.5mm_P10.16mm_Horizontal; DigiKey_Part_Number N/A
R4, R5, R8: 10k; R_Axial_DIN0207_L6.3mm_D2.5mm_P10.16mm_Horizontal
R87, R88, R89: RC0402JR-074K7L; RC0402N_YAG; DigiKey_Part_Number 311-4.7KJRCT-ND
S1: B3F-1000; SW_B3F-1000; DigiKey_Part_Number SW400-ND
S2: 416131160803; DigiKey_Part_Number 732-416131160803CT-ND
U1: LFE5U-25F-6BG256C; BGA256C80P16X16_1400X1400X170; PARTREV 2.8; DigiKey_Part_Number 220-2205-ND
U7: W25Q128JVSIQ TR; SOIC_208MIL_WIN; DigiKey_Part_Number 256-W25Q128JVSIQTRCT-ND

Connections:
3V3: C1.2, R3.1, R4.2, R5.2, R8.1, R87.1, R88.2, R89.1, U7.8 (VCC); also elsewhere on the board
CCLK: R4.1, U1.N9 (CCLK), U7.1 (/CS), U7.6 (CLK)
CFG_0: R87.2, S2.1, U1.N10 (CFG_0)
CFG_1: R89.2, S2.2, U1.P10 (CFG_1)
CFG_2: R88.1, S2.3, U1.R10 (CFG_2)
GND: R9.1, R12.2, S1.2, S2.A1, S2.A2, S2.A3, U7.4 (GND); also elsewhere on the board
MISO: U1.T7 (PB11A), U7.2 (DO(IO1))
MOSI: U1.T8 (PB11B), U7.5 (DI(IO0))
unnamed: D1.1, R9.2
unnamed: D1.2, R10.2
unnamed: D2.1, R12.1
unnamed: D2.2, R11.2
unnamed: R10.1, U1.P9 (DONE)
unnamed: C1.1, U1.L6 (VCCIO8)
unnamed: R11.1, U1.T9 (~INIT)
unnamed: R8.2, U7.7 (/HOLD_/RESET)
unnamed: R5.1, U7.3 (/WP(IO2))
PROGRAM: R3.2, S1.3, U1.R9 (~PROGRAM)

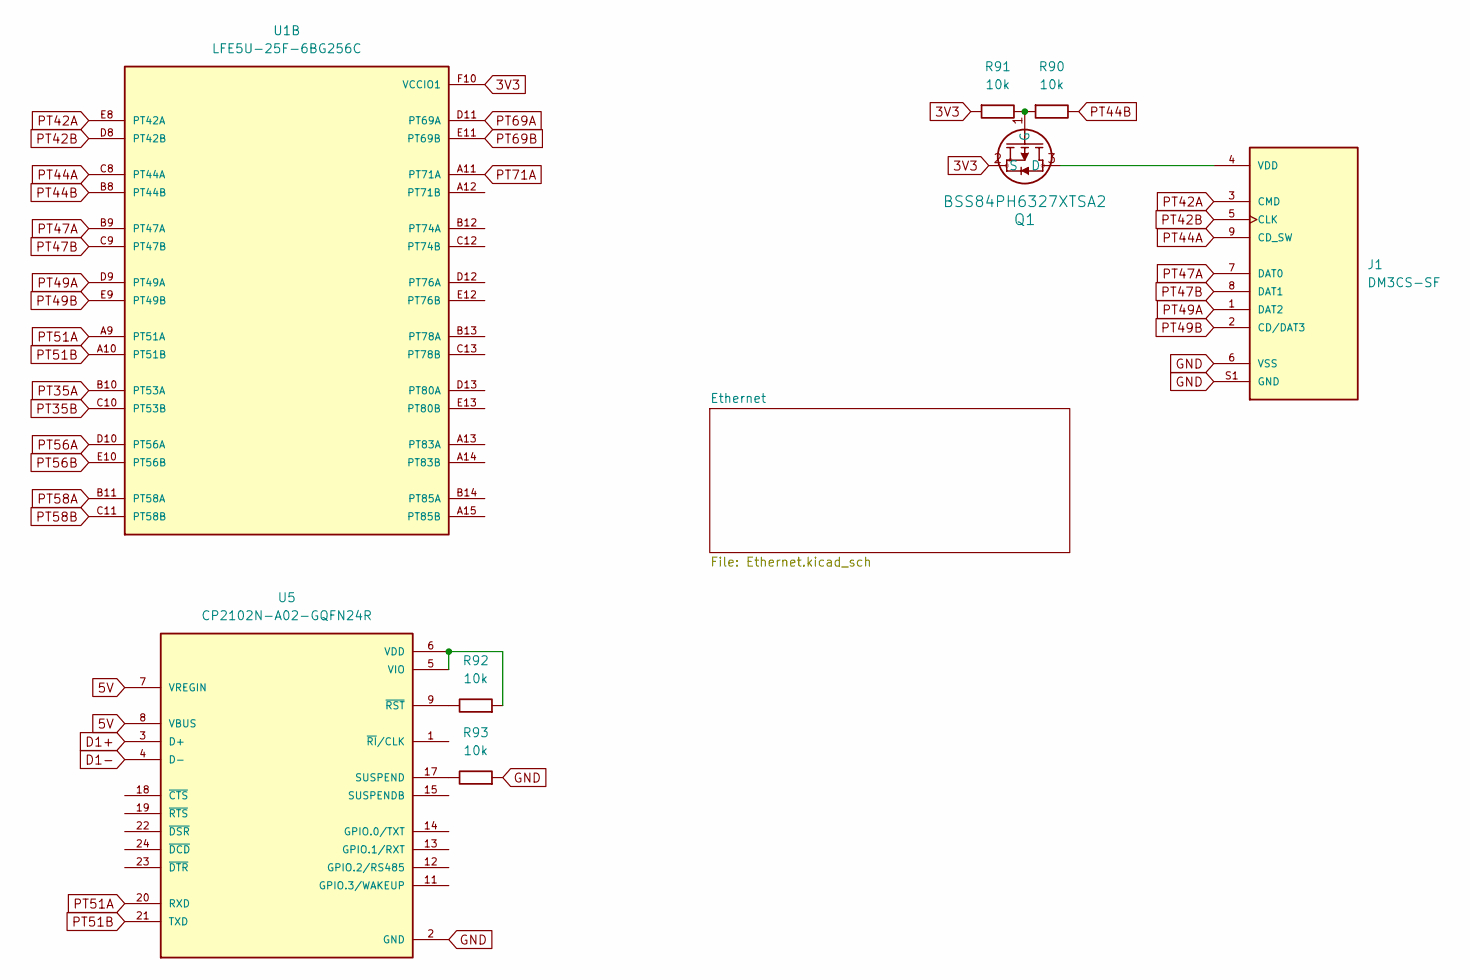
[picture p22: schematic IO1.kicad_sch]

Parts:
J1: DM3CS-SF; HRS_DM3CS-SF; PARTREV n/a; DigiKey_Part_Number HR1972CT-ND
Q1: BSS84PH6327XTSA2; SOT23_BSS84_INF; DigiKey_Part_Number BSS84PH6327XTSA2CT-ND
R90, R91, R92, R93: 10k; R_Axial_DIN0207_L6.3mm_D2.5mm_P10.16mm_Horizontal; DigiKey_Part_Number N/A
U1: LFE5U-25F-6BG256C; BGA256C80P16X16_1400X1400X170; PARTREV 2.8; DigiKey_Part_Number 220-2205-ND
U5: CP2102N-A02-GQFN24R; QFN50P400X400X80-25N; PARTREV 1.3; DigiKey_Part_Number 336-5888-1-ND

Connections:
3V3: Q1.2 (S), R91.1, U1.F10 (VCCIO1), U1.F11 (VCCIO1); also elsewhere on the board
5V: U5.7 (VREGIN), U5.8 (VBUS); also elsewhere on the board
D1+: U5.3 (D+); also elsewhere on the board
D1-: U5.4 (D-); also elsewhere on the board
GND: J1.6 (VSS), J1.S1 (GND), J1.S2 (GND), J1.S3 (GND), J1.S5 (GND), R93.1, U5.2 (GND), U5.25 (GND); also elsewhere on the board
unnamed: J1.4 (VDD), Q1.3 (D)
unnamed: Q1.1 (G), R90.1, R91.2
unnamed: R93.2, U5.17 (SUSPEND)
unnamed: R92.1, U5.5 (VIO), U5.6 (VDD)
unnamed: R92.2, U5.9 (~RST)
PT35A: U1.B10 (PT53A); also elsewhere on the board
PT35B: U1.C10 (PT53B); also elsewhere on the board
PT42A: J1.3 (CMD), U1.E8 (PT42A)
PT42B: J1.5 (CLK), U1.D8 (PT42B)
PT44A: J1.9 (CD_SW), U1.C8 (PT44A)
PT44B: R90.2, U1.B8 (PT44B)
PT47A: J1.7 (DAT0), U1.B9 (PT47A)
PT47B: J1.8 (DAT1), U1.C9 (PT47B)
PT49A: J1.1 (DAT2), U1.D9 (PT49A)
PT49B: J1.2 (CD/DAT3), U1.E9 (PT49B)
PT51A: U1.A9 (PT51A), U5.20 (RXD)
PT51B: U1.A10 (PT51B), U5.21 (TXD)
PT56A: U1.D10 (PT56A); also elsewhere on the board
PT56B: U1.E10 (PT56B); also elsewhere on the board
PT58A: U1.B11 (PT58A); also elsewhere on the board
PT58B: U1.C11 (PT58B); also elsewhere on the board
PT69A: U1.D11 (PT69A); also elsewhere on the board
PT69B: U1.E11 (PT69B); also elsewhere on the board
PT71A: U1.A11 (PT71A); also elsewhere on the board

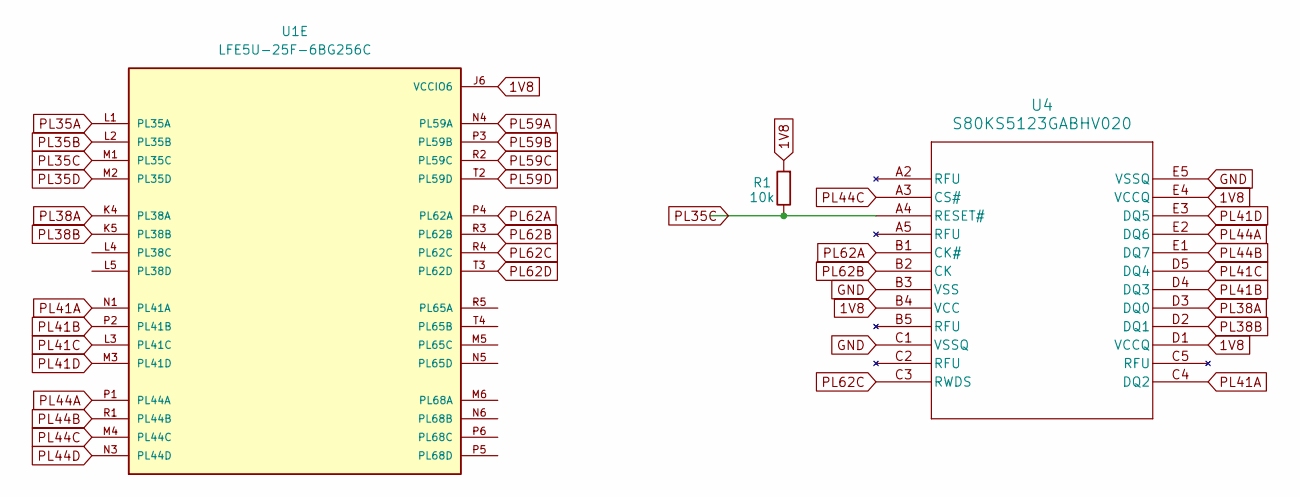
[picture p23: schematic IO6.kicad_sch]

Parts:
R1: 10k; R_Axial_DIN0207_L6.3mm_D2.5mm_P10.16mm_Horizontal
U1: LFE5U-25F-6BG256C; BGA256C80P16X16_1400X1400X170; PARTREV 2.8; DigiKey_Part_Number 220-2205-ND
U4: S80KS5123GABHV020; PG-BGA-24-801

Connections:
1V8: R1.1, U1.J6 (VCCIO6), U1.J7 (VCCIO6), U4.B4 (VCC), U4.D1 (VCCQ), U4.E4 (VCCQ); also elsewhere on the board
GND: U4.B3 (VSS), U4.C1 (VSSQ), U4.E5 (VSSQ); also elsewhere on the board
PL35A: U1.L1 (PL35A)
PL35B: U1.L2 (PL35B)
PL35C: R1.2, U1.M1 (PL35C), U4.A4 (RESET#)
PL35D: U1.M2 (PL35D); also elsewhere on the board
PL38A: U1.K4 (PL38A), U4.D3 (DQ0)
PL38B: U1.K5 (PL38B), U4.D2 (DQ1)
PL41A: U1.N1 (PL41A), U4.C4 (DQ2)
PL41B: U1.P2 (PL41B), U4.D4 (DQ3)
PL41C: U1.L3 (PL41C), U4.D5 (DQ4)
PL41D: U1.M3 (PL41D), U4.E3 (DQ5)
PL44A: U1.P1 (PL44A), U4.E2 (DQ6)
PL44B: U1.R1 (PL44B), U4.E1 (DQ7)
PL44C: U1.M4 (PL44C), U4.A3 (CS#)
PL44D: U1.N3 (PL44D)
PL59A: U1.N4 (PL59A)
PL59B: U1.P3 (PL59B)
PL59C: U1.R2 (PL59C)
PL59D: U1.T2 (PL59D)
PL62A: U1.P4 (PL62A), U4.B1 (CK#)
PL62B: U1.R3 (PL62B), U4.B2 (CK)
PL62C: U1.R4 (PL62C), U4.C3 (RWDS)
PL62D: U1.T3 (PL62D)

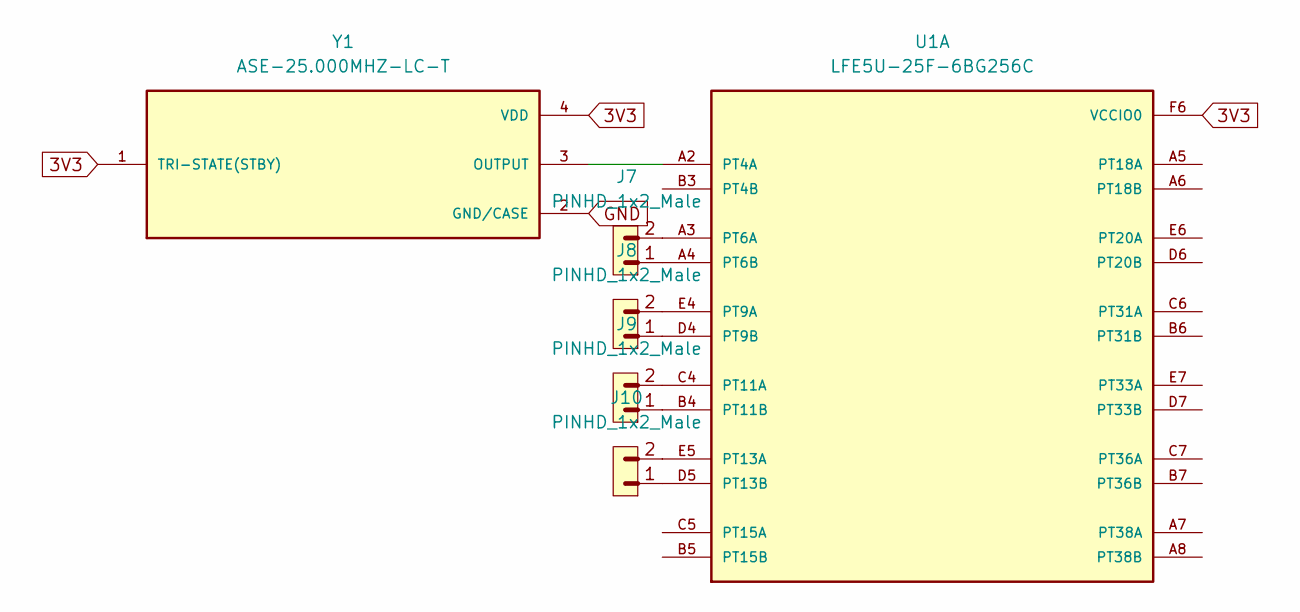
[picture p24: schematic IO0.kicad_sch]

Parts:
J7, J8, J9, J10: PINHD_1x2_Male; PinHeader_1x02_P2.54mm_Vertical
U1: LFE5U-25F-6BG256C; BGA256C80P16X16_1400X1400X170; PARTREV 2.8; DigiKey_Part_Number 220-2205-ND
Y1: ASE-25.000MHZ-LC-T; XTAL_ASE-25.000MHZ-LC-T; PARTREV 02-18-22; DigiKey_Part_Number 535-ASE-25.000MHZ-L-C-TCT-ND

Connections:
3V3: U1.F6 (VCCIO0), U1.F7 (VCCIO0), Y1.1 (TRI-STATE(STBY)), Y1.4 (VDD); also elsewhere on the board
GND: Y1.2 (GND/CASE); also elsewhere on the board
unnamed: U1.A2 (PT4A), Y1.3 (OUTPUT)
unnamed: J7.2, U1.A3 (PT6A)
unnamed: J7.1, U1.A4 (PT6B)
unnamed: J8.2, U1.E4 (PT9A)
unnamed: J8.1, U1.D4 (PT9B)
unnamed: J9.2, U1.C4 (PT11A)
unnamed: J9.1, U1.B4 (PT11B)
unnamed: J10.2, U1.E5 (PT13A)
unnamed: J10.1, U1.D5 (PT13B)

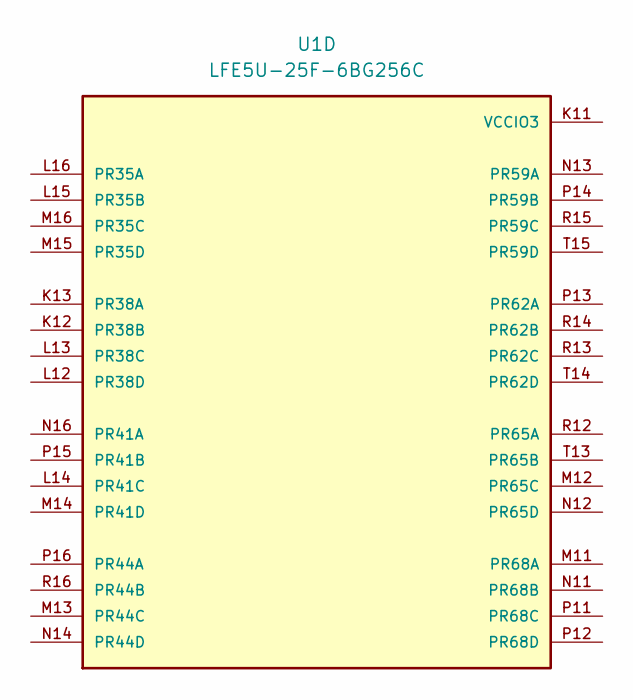
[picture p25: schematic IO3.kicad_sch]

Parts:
U1: LFE5U-25F-6BG256C; BGA256C80P16X16_1400X1400X170; PARTREV 2.8; DigiKey_Part_Number 220-2205-ND

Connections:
VCCIO3: U1.K11 (VCCIO3), U1.L11 (VCCIO3)

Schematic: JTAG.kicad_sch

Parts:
J3: PINHD_1x6_Male; PinHeader_1x06_P2.54mm_Vertical
R13, R14: 10k; R_Axial_DIN0207_L6.3mm_D2.5mm_P10.16mm_Horizontal
U1: LFE5U-25F-6BG256C; BGA256C80P16X16_1400X1400X170; PARTREV 2.8; DigiKey_Part_Number 220-2205-ND

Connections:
1V2: J3.5; also elsewhere on the board
3V3: R13.1, R14.1; also elsewhere on the board
GND: J3.6; also elsewhere on the board
unnamed: J3.4, U1.T10 (TCK)
unnamed: J3.2, R14.2, U1.R11 (TDI)
unnamed: J3.3, U1.M10 (TDO)
unnamed: J3.1, R13.2, U1.T11 (TMS)

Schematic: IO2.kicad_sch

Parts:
J5: PINHD_1x16_Male; PinHeader_1x16_P2.54mm_Vertical
J6: PINHD_1x6_Male; PinHeader_1x06_P2.54mm_Vertical
U1: LFE5U-25F-6BG256C; BGA256C80P16X16_1400X1400X170; PARTREV 2.8; DigiKey_Part_Number 220-2205-ND

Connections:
3V3\: U1.H11 (VCCIO2), U1.J11 (VCCIO2)
unnamed: J5.16, U1.B16 (PR11A)
unnamed: J5.15, U1.B15 (PR11B)
unnamed: J5.14, U1.C14 (PR11C)
unnamed: J5.13, U1.D14 (PR11D)
unnamed: J5.12, U1.C16 (PR14A)
unnamed: J5.11, U1.C15 (PR14B)
unnamed: J5.10, U1.E14 (PR14C)
unnamed: J5.9, U1.F14 (PR14D)
unnamed: J5.8, U1.D16 (PR17A)
unnamed: J5.7, U1.E15 (PR17B)
unnamed: J5.6, U1.F13 (PR17C)
unnamed: J5.5, U1.F12 (PR17D)
unnamed: J5.4, U1.G12 (PR20A)
unnamed: J5.3, U1.G13 (PR20B)
unnamed: J5.2, U1.F15 (PR20C)
unnamed: J5.1, U1.E16 (PR20D)

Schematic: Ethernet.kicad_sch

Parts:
C2, C3: CC0402JRNPO9BN220; CAPC1005X55N; DigiKey_Part_Number 311-1018-1-ND
C4: GRM022D80G104ME15L; CAPC0402X22N; DigiKey_Part_Number 490-10386-1-ND
J4: 2041411-1; TE_2041411-1; PARTREV A; DigiKey_Part_Number A135635CT-ND
R15, R16: 10k; R_Axial_DIN0207_L6.3mm_D2.5mm_P10.16mm_Horizontal
U2: LAN8720A-CP-TR; QFN24-6X6_MC_MCH
Y2: ECS-250-18-23A-EN-TR; XTAL_ECS-250-18-23A-EN-TR; DigiKey_Part_Number XC1671CT-ND

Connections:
3V3: R15.2, U2.1 (VDD2A), U2.9 (VDDIO), U2.19 (VDD1A); also elsewhere on the board
GND: C2.2, C3.2, C4.1, J4.9, J4.12, J4.S1 (SHIELD), J4.S2 (SHIELD), R16.2, U2.10 (RXER/*PHYAD0); also elsewhere on the board
LED1: J4.11, U2.3 (LED1/*REGOFF)
LED2: J4.10, U2.2 (LED2/*NINTSEL)
unnamed: R15.1, U2.15 (NRST)
unnamed: R16.1, U2.24 (RBIAS)
unnamed: C4.2, U2.6 (VDDCR)
unnamed: C2.1, U2.5 (XTAL1/CLKIN), Y2.1
unnamed: C3.1, U2.4 (XTAL2), Y2.2
PT35A: U2.17 (TXD0); also elsewhere on the board
PT35B: U2.18 (TXD1); also elsewhere on the board
PT56A: U2.16 (TXEN); also elsewhere on the board
PT56B: U2.11 (CRS_DV/*MODE2); also elsewhere on the board
PT58A: U2.8 (RXD0/*MODE0); also elsewhere on the board
PT58B: U2.7 (RXD1/*MODE1); also elsewhere on the board
PT69A: U2.13 (MDC); also elsewhere on the board
PT69B: U2.12 (MDIO); also elsewhere on the board
PT71A: U2.14 (NINT/REFCLKO); also elsewhere on the board
RXN: J4.6, U2.22 (RXN)
RXP: J4.3, U2.23 (RXP)
TXN: J4.2, U2.20 (TXN)
TXP: J4.1, U2.21 (TXP)

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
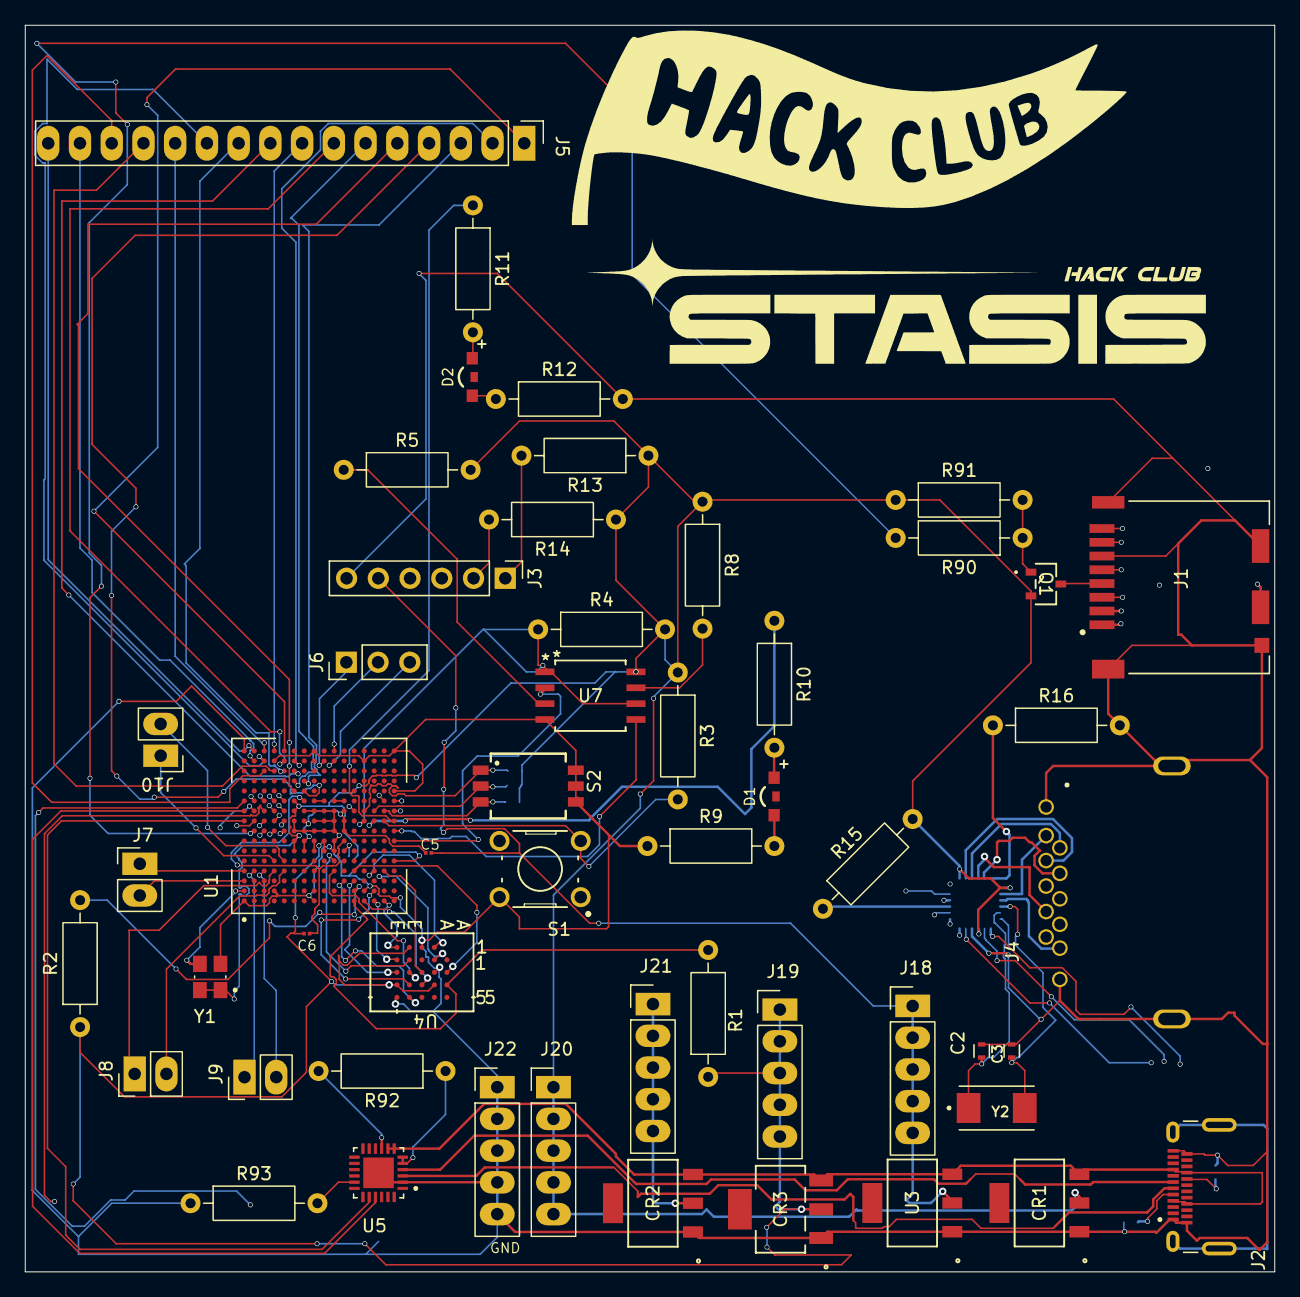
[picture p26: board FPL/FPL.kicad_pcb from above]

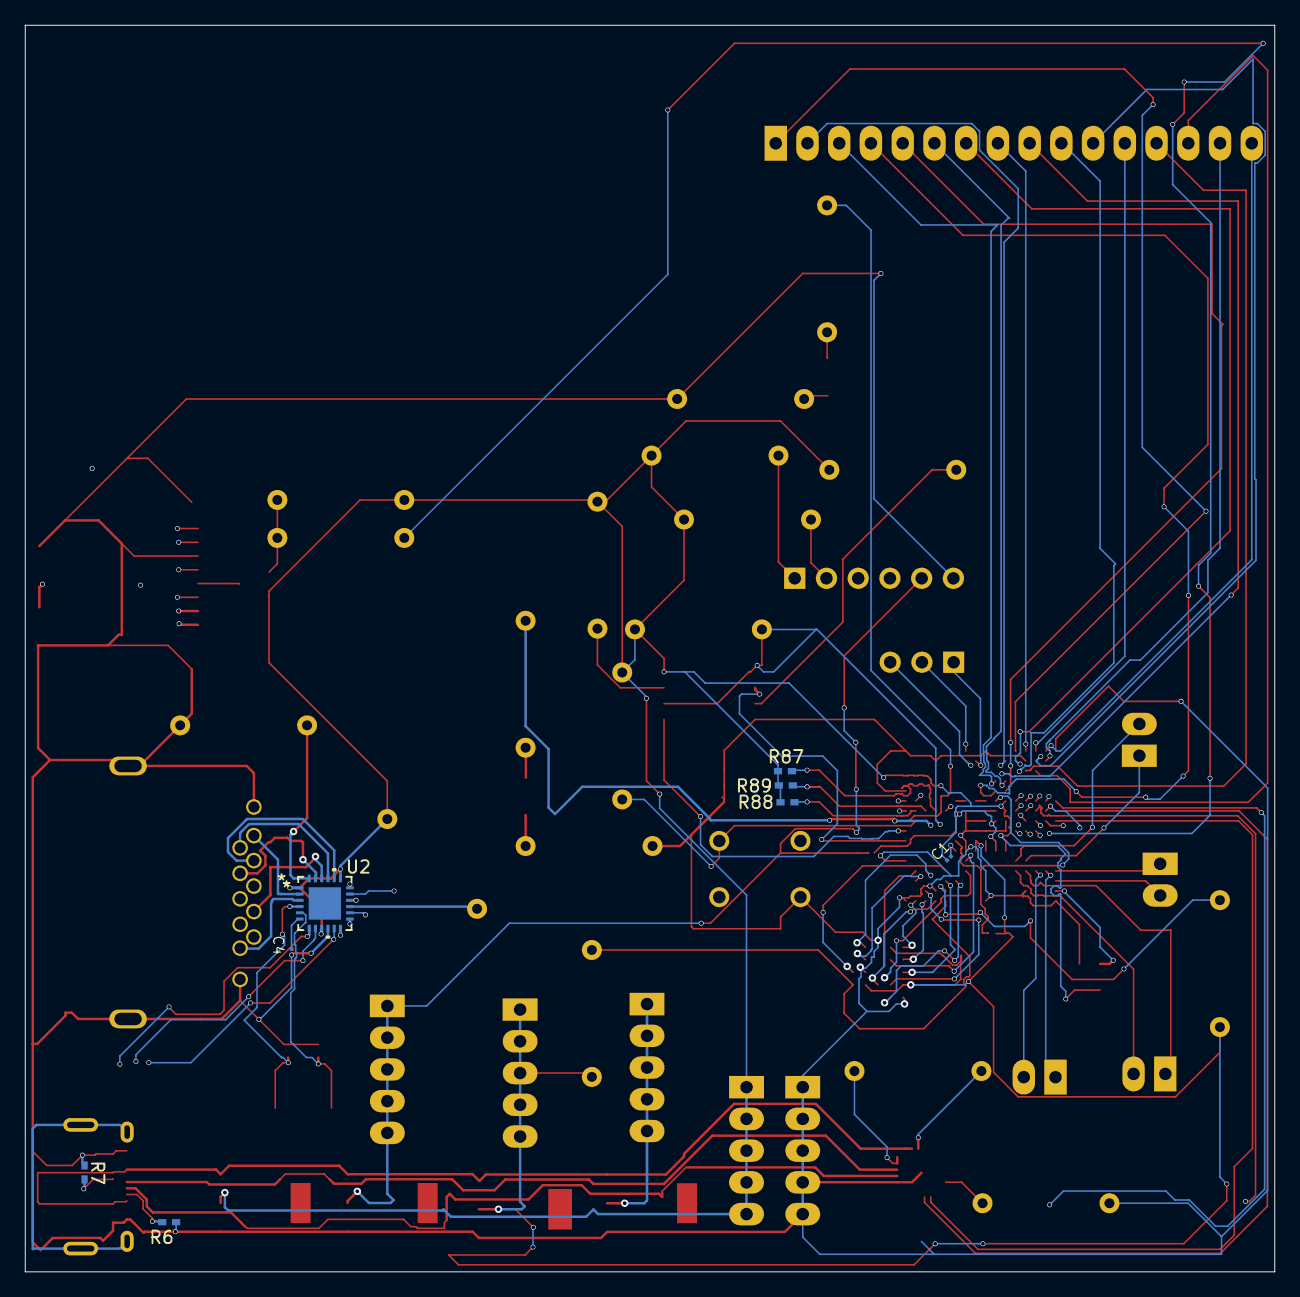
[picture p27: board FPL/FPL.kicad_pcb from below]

Board: 4 copper layers, 100.0 x 99.8 mm, 60 parts (8 on the bottom side), 113 nets.

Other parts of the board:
R2: 10k; R_Axial_DIN0207_L6.3mm_D2.5mm_P10.16mm_Horizontal

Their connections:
1V8: R2.1; also elsewhere on the board
PL35D: R2.2; also elsewhere on the board

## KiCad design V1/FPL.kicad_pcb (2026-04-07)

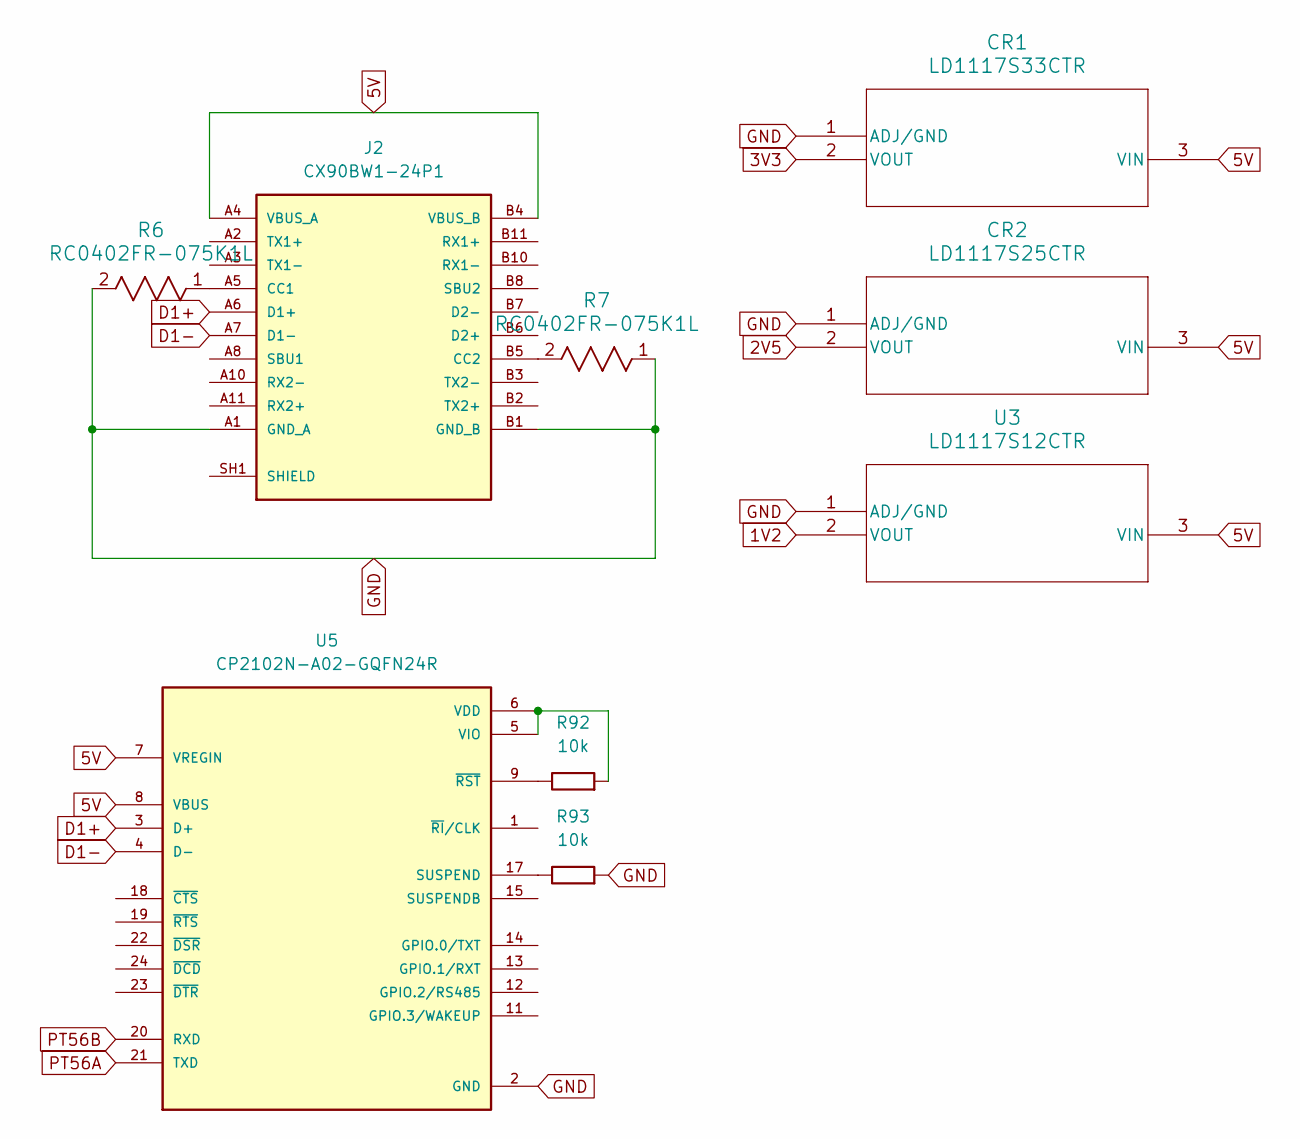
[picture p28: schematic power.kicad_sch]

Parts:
CR1: LD1117S33CTR; SOT-223_STM; DigiKey_Part_Number LD1117S33CTR
CR2: LD1117S25CTR; SOT-223_STM; DigiKey_Part_Number LD1117S25CTR
J2: CX90BW1-24P1; HIROSE_CX90BW1-24P1; PARTREV 24.05.01; DigiKey_Part_Number 26-CX90BW1-24P1CT-ND
R6, R7: RC0402FR-075K1L; RC0402N_YAG; DigiKey_Part_Number 311-5.10KLRCT-ND
R92, R93: 10k; R_Axial_DIN0207_L6.3mm_D2.5mm_P10.16mm_Horizontal; DigiKey_Part_Number N/A
U3: LD1117S12CTR; SOT-223_STM; DigiKey_Part_Number LD1117S12CTR
U5: CP2102N-A02-GQFN24R; QFN50P400X400X80-25N; PARTREV 1.3; DigiKey_Part_Number 336-5888-1-ND

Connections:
1V2: U3.2 (VOUT); also elsewhere on the board
2V5: CR2.2 (VOUT); also elsewhere on the board
3V3: CR1.2 (VOUT); also elsewhere on the board
5V: CR1.3 (VIN), CR2.3 (VIN), J2.A4 (VBUS_A), J2.A9 (VBUS_A), J2.B4 (VBUS_B), J2.B9 (VBUS_B), U3.3 (VIN), U5.7 (VREGIN), U5.8 (VBUS); also elsewhere on the board
D1+: J2.A6 (D1+), U5.3 (D+)
D1-: J2.A7 (D1-), U5.4 (D-)
GND: CR1.1 (ADJ/GND), CR2.1 (ADJ/GND), J2.A1 (GND_A), J2.A12 (GND_A), J2.B1 (GND_B), J2.B12 (GND_B), R6.2, R7.1, R93.1, U3.1 (ADJ/GND), U5.2 (GND), U5.25 (GND); also elsewhere on the board
unnamed: J2.A5 (CC1), R6.1
unnamed: J2.B5 (CC2), R7.2
unnamed: J2.SH1 (SHIELD), J2.SH2 (SHIELD), J2.SH3 (SHIELD), J2.SH4 (SHIELD)
unnamed: R93.2, U5.17 (SUSPEND)
unnamed: R92.1, U5.5 (VIO), U5.6 (VDD)
unnamed: R92.2, U5.9 (~RST)
PT56A: U5.21 (TXD); also elsewhere on the board
PT56B: U5.20 (RXD); also elsewhere on the board

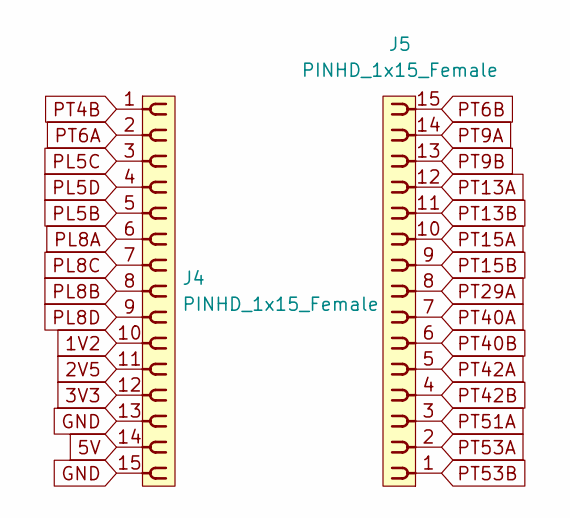
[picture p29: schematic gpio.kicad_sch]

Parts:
J4, J5: PINHD_1x15_Female; PinSocket_1x15_P2.54mm_Vertical

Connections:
1V2: J4.10; also elsewhere on the board
2V5: J4.11; also elsewhere on the board
3V3: J4.12; also elsewhere on the board
5V: J4.14; also elsewhere on the board
GND: J4.13, J4.15; also elsewhere on the board
PL5B: J4.5; also elsewhere on the board
PL5C: J4.3; also elsewhere on the board
PL5D: J4.4; also elsewhere on the board
PL8A: J4.6; also elsewhere on the board
PL8B: J4.8; also elsewhere on the board
PL8C: J4.7; also elsewhere on the board
PL8D: J4.9; also elsewhere on the board
PT4B: J4.1; also elsewhere on the board
PT6A: J4.2; also elsewhere on the board
PT6B: J5.15; also elsewhere on the board
PT9A: J5.14; also elsewhere on the board
PT9B: J5.13; also elsewhere on the board
PT13A: J5.12; also elsewhere on the board
PT13B: J5.11; also elsewhere on the board
PT15A: J5.10; also elsewhere on the board
PT15B: J5.9; also elsewhere on the board
PT29A: J5.8; also elsewhere on the board
PT40A: J5.7; also elsewhere on the board
PT40B: J5.6; also elsewhere on the board
PT42A: J5.5; also elsewhere on the board
PT42B: J5.4; also elsewhere on the board
PT51A: J5.3; also elsewhere on the board
PT53A: J5.2; also elsewhere on the board
PT53B: J5.1; also elsewhere on the board

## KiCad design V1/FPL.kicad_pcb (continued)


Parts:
C1, C2, C3, C4, C5, C6, C7, C8, C9, C10, C11, C12, C13, C14, C15, C16, C17, C18, C19: GRM022D80G104ME15L; CAPC0402X22N; DigiKey_Part_Number 490-10386-1-ND
D1, D2: WL-SMSW_1204_A; DigiKey_Part_Number 732-12022-1-ND
IC1: LFE5U-25F-6TG144C; QFP50P2200X2200X160-144N; Manufacturer_Part_Number LFE5U-25F-6TG144C; Mouser Part Number 842-LFE5U25F6TG144C
J3: JATG; PinHeader_1x07_P2.54mm_Vertical
R1, R2, R3, R4, R5: 10k; R_Axial_DIN0207_L6.3mm_D2.5mm_P10.16mm_Horizontal; DigiKey_Part_Number N/A
R8: RC0402JR-074K7L; RESC1005X40N; DigiKey_Part_Number 311-4.7KJRCT-ND
R87, R88, R89: RC0402JR-074K7L; RC0402N_YAG; DigiKey_Part_Number 311-4.7KJRCT-ND
S1: B3F-1000; SW_B3F-1000; DigiKey_Part_Number SW400-ND
S2: 416131160803; DigiKey_Part_Number 732-416131160803CT-ND
Y1: ASE-25.000MHZ-LC-T; XTAL_ASE-25.000MHZ-LC-T; PARTREV 02-18-22; DigiKey_Part_Number 535-ASE-25.000MHZ-L-C-TCT-ND

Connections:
1V1: J3.2
1V2: C4.1, C5.1, C8.1, C11.1, C14.1, C18.1; also elsewhere on the board
2V5: C3.1, C10.1, C15.1, IC1.132 (VCCAUX_4); also elsewhere on the board
3V3: C1.1, C2.1, C6.1, C7.1, C9.1, C12.1, C13.1, C16.1, C17.1, C19.1, J3.7, R1.1, R8.1, R87.1, R88.2, R89.1, Y1.1 (TRI-STATE(STBY)), Y1.4 (VDD); also elsewhere on the board
CCLK: IC1.54 (CCLK)
CFG_0: IC1.62 (CFG_0), R87.2, S2.1
CFG_1: IC1.59 (CFG_1), R89.2, S2.2
CFG_2: IC1.58 (CFG_2), R88.1, S2.3
GND: IC1.8 (GND_1), IC1.15 (GND_2), IC1.21 (GND_3), IC1.42 (GND_4), IC1.65 (GND_5), IC1.75 (GND_6), IC1.85 (GND_7), IC1.87 (GND_8), IC1.101 (GND_9), IC1.123 (GND_10), IC1.129 (GND_11), IC1.131 (GND_12), IC1.138 (GND_13), J3.1, R3.1, R5.2, S1.2, S2.A1, S2.A2, S2.A3, Y1.2 (GND/CASE); also elsewhere on the board
unnamed: D1.1, R3.2
unnamed: D1.2, R2.2
unnamed: D2.1, R5.1
unnamed: D2.2, R4.2
unnamed: IC1.56 (DONE), R4.1
unnamed: IC1.55 (INITN), R2.1
unnamed: C3.2, IC1.17 (VCCAUX_1)
unnamed: C10.2, IC1.53 (VCCAUX_2)
unnamed: C15.2, IC1.96 (VCCAUX_3)
unnamed: C19.2, IC1.137 (VCCIO0)
unnamed: C17.2, IC1.122 (VCCIO1)
unnamed: C13.2, IC1.100 (VCCIO2)
unnamed: C12.2, IC1.70 (VCCIO3_1)
unnamed: C16.2, IC1.86 (VCCIO3_2)
unnamed: C2.2, IC1.16 (VCCIO6_1)
unnamed: C7.2, IC1.36 (VCCIO6_2)
unnamed: C1.2, IC1.9 (VCCIO7)
unnamed: C9.2, IC1.43 (VCCIO8)
unnamed: C4.2, IC1.20 (VCC_1)
unnamed: C5.2, IC1.29 (VCC_2)
unnamed: C8.2, IC1.38 (VCC_3)
unnamed: C11.2, IC1.66 (VCC_4)
unnamed: C14.2, IC1.83 (VCC_5)
unnamed: C18.2, IC1.130 (VCC_6)
unnamed: C6.2, IC1.32 (VSSIO6)
PB4A: IC1.40 (PB4A); also elsewhere on the board
PB4B: IC1.44 (PB4B); also elsewhere on the board
PB6A: IC1.39 (PB6A); also elsewhere on the board
PB6B: IC1.41 (PB6B); also elsewhere on the board
PB9A: IC1.45 (PB9A); also elsewhere on the board
PB11A: IC1.46 (PB11A); also elsewhere on the board
PB11B: IC1.47 (PB11B); also elsewhere on the board
PB13A: IC1.48 (PB13A); also elsewhere on the board
PB13B: IC1.50 (PB13B); also elsewhere on the board
PB15A: IC1.49 (PB15A); also elsewhere on the board
PB15B: IC1.51 (PB15B); also elsewhere on the board
PB18A: IC1.52 (PB18A); also elsewhere on the board
PCLK: IC1.10 (PL14A), Y1.3 (OUTPUT)
PL5B: IC1.3 (PL5B); also elsewhere on the board
PL5C: IC1.1 (PL5C); also elsewhere on the board
PL5D: IC1.2 (PL5D); also elsewhere on the board
PL8A: IC1.4 (PL8A); also elsewhere on the board
PL8B: IC1.6 (PL8B); also elsewhere on the board
PL8C: IC1.5 (PL8C); also elsewhere on the board
PL8D: IC1.7 (PL8D); also elsewhere on the board
PL14B: IC1.12 (PL14B); also elsewhere on the board
PL14C: IC1.11 (PL14C); also elsewhere on the board
PL14D: IC1.13 (PL14D); also elsewhere on the board
PL23D: IC1.14 (PL23D); also elsewhere on the board
PL32B: IC1.18 (PL32B); also elsewhere on the board
PL35B: IC1.19 (PL35B); also elsewhere on the board
PL35C: IC1.22 (PL35C); also elsewhere on the board
PL35D: IC1.23 (PL35D); also elsewhere on the board
PL38A: IC1.24 (PL38A); also elsewhere on the board
PL38B: IC1.25 (PL38B); also elsewhere on the board
PL41C: IC1.26 (PL41C); also elsewhere on the board
PL41D: IC1.27 (PL41D); also elsewhere on the board
PL44A: IC1.28 (PL44A); also elsewhere on the board
PL44B: IC1.30 (PL44B); also elsewhere on the board
PL44C: IC1.31 (PL44C); also elsewhere on the board
PL44D: IC1.33 (PL44D); also elsewhere on the board
PL47A: IC1.34 (PL47A); also elsewhere on the board
PL47B: IC1.35 (PL47B); also elsewhere on the board
PL47C: IC1.37 (PL47C); also elsewhere on the board
PR2B: IC1.108 (PR2B); also elsewhere on the board
PR2C: IC1.107 (PR2C); also elsewhere on the board
PR2D: IC1.106 (PR2D); also elsewhere on the board
PR8A: IC1.105 (PR8A); also elsewhere on the board
PR8B: IC1.103 (PR8B); also elsewhere on the board
PR8C: IC1.104 (PR8C); also elsewhere on the board
PR8D: IC1.102 (PR8D); also elsewhere on the board
PR14A: IC1.99 (PR14A); also elsewhere on the board
PR14B: IC1.97 (PR14B); also elsewhere on the board
PR14C: IC1.98 (PR14C); also elsewhere on the board
PR20A: IC1.95 (PR20A); also elsewhere on the board
PR20B: IC1.93 (PR20B); also elsewhere on the board
PR20C: IC1.94 (PR20C); also elsewhere on the board
PR20D: IC1.92 (PR20D); also elsewhere on the board
PR23A: IC1.91 (PR23A); also elsewhere on the board
PR23B: IC1.89 (PR23B); also elsewhere on the board
PR23C: IC1.90 (PR23C); also elsewhere on the board
PR23D: IC1.88 (PR23D)
PR32C: IC1.84 (PR32C); also elsewhere on the board
PR32D: IC1.82 (PR32D); also elsewhere on the board
PR35A: IC1.81 (PR35A); also elsewhere on the board
PR35B: IC1.79 (PR35B); also elsewhere on the board
PR35C: IC1.80 (PR35C); also elsewhere on the board
PR35D: IC1.78 (PR35D); also elsewhere on the board
PR41A: IC1.77 (PR41A); also elsewhere on the board
PR41B: IC1.76 (PR41B); also elsewhere on the board
PR41C: IC1.74 (PR41C); also elsewhere on the board
PR41D: IC1.73 (PR41D); also elsewhere on the board
PR44C: IC1.72 (PR44C); also elsewhere on the board
PR47A: IC1.71 (PR47A); also elsewhere on the board
PR47B: IC1.67 (PR47B); also elsewhere on the board
PR47C: IC1.69 (PR47C); also elsewhere on the board
PR47D: IC1.68 (PR47D); also elsewhere on the board
PT4B: IC1.142 (PT4B); also elsewhere on the board
PT6A: IC1.143 (PT6A); also elsewhere on the board
PT6B: IC1.141 (PT6B); also elsewhere on the board
PT9A: IC1.140 (PT9A); also elsewhere on the board
PT9B: IC1.139 (PT9B); also elsewhere on the board
PT13A: IC1.136 (PT13A); also elsewhere on the board
PT13B: IC1.135 (PT13B); also elsewhere on the board
PT15A: IC1.134 (PT15A); also elsewhere on the board
PT15B: IC1.133 (PT15B); also elsewhere on the board
PT29A: IC1.128 (PT29A); also elsewhere on the board
PT40A: IC1.127 (PT40A); also elsewhere on the board
PT40B: IC1.126 (PT40B); also elsewhere on the board
PT42A: IC1.125 (PT42A); also elsewhere on the board
PT42B: IC1.124 (PT42B); also elsewhere on the board
PT51A: IC1.121 (PT51A); also elsewhere on the board
PT53A: IC1.120 (PT53A); also elsewhere on the board
PT53B: IC1.119 (PT53B); also elsewhere on the board
PT56A: IC1.118 (PT56A); also elsewhere on the board
PT56B: IC1.117 (PT56B); also elsewhere on the board
PT58A: IC1.116 (PT58A); also elsewhere on the board
PT58B: IC1.115 (PT58B); also elsewhere on the board
PT60A: IC1.114 (PT60A); also elsewhere on the board
PT60B: IC1.113 (PT60B); also elsewhere on the board
PT62A: IC1.112 (PT62A); also elsewhere on the board
PT62B: IC1.111 (PT62B); also elsewhere on the board
PT67A: IC1.110 (PT67A); also elsewhere on the board
RST: IC1.57 (PROGRAMN), R1.2, S1.3
TCK: IC1.63 (TCK), J3.5
TDI: IC1.61 (TDI), J3.4
TDO: IC1.60 (TDO), J3.3
TMS: IC1.64 (TMS), J3.6, R8.2


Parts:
J1: DM3CS-SF; HRS_DM3CS-SF; PARTREV n/a; DigiKey_Part_Number HR1972CT-ND
Q1: BSS84PH6327XTSA2; SOT23_BSS84_INF; DigiKey_Part_Number BSS84PH6327XTSA2CT-ND
R90, R91: 10k; R_Axial_DIN0207_L6.3mm_D2.5mm_P10.16mm_Horizontal; DigiKey_Part_Number N/A
U4: W25Q128JVSIQ TR; SOIC_208MIL_WIN; DigiKey_Part_Number 256-W25Q128JVSIQTRCT-ND

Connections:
3V3: Q1.2 (S), R91.1, U4.8 (VCC); also elsewhere on the board
GND: J1.6 (VSS), J1.S1 (GND), J1.S2 (GND), J1.S3 (GND), J1.S5 (GND), U4.4 (GND); also elsewhere on the board
unnamed: J1.4 (VDD), Q1.3 (D)
unnamed: Q1.1 (G), R90.1, R91.2
PR2B: R90.2; also elsewhere on the board
PR2C: U4.5 (DI(IO0)); also elsewhere on the board
PR2D: U4.6 (CLK); also elsewhere on the board
PR8A: U4.7 (/HOLD_/RESET); also elsewhere on the board
PR8B: U4.2 (DO(IO1)); also elsewhere on the board
PR8C: U4.3 (/WP(IO2)); also elsewhere on the board
PR8D: U4.1 (/CS); also elsewhere on the board
PT58A: J1.7 (DAT0); also elsewhere on the board
PT58B: J1.2 (CD/DAT3); also elsewhere on the board
PT60A: J1.1 (DAT2); also elsewhere on the board
PT60B: J1.8 (DAT1); also elsewhere on the board
PT62A: J1.9 (CD_SW); also elsewhere on the board
PT62B: J1.5 (CLK); also elsewhere on the board
PT67A: J1.3 (CMD); also elsewhere on the board


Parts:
C20, C21, C22, C23: GRM022D80G104ME15L; CAPC0402X22N; DigiKey_Part_Number 490-10386-1-ND
R9, R10, R11, R12, R13, R14, R15, R16, R17, R18, R19, R20, R21, R22, R23, R24, R25, R26, R27, R28, R29, R30, R31, R32, R33, R34, R35, R36, R37, R38, R39, R40, R41, R42, R43, R44, R45, R46, R47, R48, R49, R50, R51, R52, R53, R54, R55, R56, R57, R58, R59, R60, R61, R62, R63, R64, R65, R66, R67, R68, R69, R70, R71, R72, R73, R74, R75, R76, R77, R78, R79, R80, R81, R82, R83, R84, R85, R86: KTR10EZPJ470; RES_ERJXGNF47R0Y; DigiKey_Part_Number RHM47BCT-ND
U1, U2: W9825G6KH-6; SOP80P1176X120-54N; PARTREV A05; DigiKey_Part_Number W9825G6KH-6-ND

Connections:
3V3: C20.1, C21.1, C22.1, C23.1; also elsewhere on the board
GND: U1.6 (VSSQ), U1.12 (VSSQ), U1.28 (VSS), U1.41 (VSS), U1.46 (VSSQ), U1.52 (VSSQ), U1.54 (VSS), U2.6 (VSSQ), U2.12 (VSSQ), U2.28 (VSS), U2.41 (VSS), U2.46 (VSSQ), U2.52 (VSSQ), U2.54 (VSS); also elsewhere on the board
unnamed: R31.2, U1.23 (A0)
unnamed: R30.2, U1.24 (A1)
unnamed: R29.2, U1.25 (A2)
unnamed: R28.2, U1.26 (A3)
unnamed: R27.2, U1.29 (A4)
unnamed: R26.2, U1.30 (A5)
unnamed: R25.2, U1.31 (A6)
unnamed: R24.2, U1.32 (A7)
unnamed: R23.2, U1.33 (A8)
unnamed: R22.2, U1.34 (A9)
unnamed: R21.2, U1.22 (A10/AP)
unnamed: R20.2, U1.35 (A11)
unnamed: R19.2, U1.36 (A12)
unnamed: R10.2, U1.20 (BS0)
unnamed: R9.2, U1.21 (BS1)
unnamed: R14.2, U1.37 (CKE)
unnamed: R13.2, U1.38 (CLK)
unnamed: R47.1, U1.2 (DQ0)
unnamed: R46.1, U1.4 (DQ1)
unnamed: R45.1, U1.5 (DQ2)
unnamed: R44.1, U1.7 (DQ3)
unnamed: R43.1, U1.8 (DQ4)
unnamed: R42.1, U1.10 (DQ5)
unnamed: R41.1, U1.11 (DQ6)
unnamed: R40.1, U1.13 (DQ7)
unnamed: R39.1, U1.42 (DQ8)
unnamed: R38.1, U1.44 (DQ9)
unnamed: R37.1, U1.45 (DQ10)
unnamed: R36.1, U1.47 (DQ11)
unnamed: R35.1, U1.48 (DQ12)
unnamed: R34.1, U1.50 (DQ13)
unnamed: R33.1, U1.51 (DQ14)
unnamed: R32.1, U1.53 (DQ15)
unnamed: R12.2, U1.15 (LDQM)
unnamed: R11.2, U1.39 (UDQM)
unnamed: R17.2, U1.17 (~CAS)
unnamed: R16.2, U1.19 (~CS)
unnamed: R18.2, U1.18 (~RAS)
unnamed: R15.2, U1.16 (~WE)
unnamed: R48.2, U2.23 (A0)
unnamed: R49.2, U2.24 (A1)
unnamed: R50.2, U2.25 (A2)
unnamed: R51.2, U2.26 (A3)
unnamed: R52.2, U2.29 (A4)
unnamed: R53.2, U2.30 (A5)
unnamed: R54.2, U2.31 (A6)
unnamed: R55.2, U2.32 (A7)
unnamed: R56.2, U2.33 (A8)
unnamed: R57.2, U2.34 (A9)
unnamed: R58.2, U2.22 (A10/AP)
unnamed: R59.2, U2.35 (A11)
unnamed: R60.2, U2.36 (A12)
unnamed: R69.2, U2.20 (BS0)
unnamed: R70.2, U2.21 (BS1)
unnamed: R65.2, U2.37 (CKE)
unnamed: R66.2, U2.38 (CLK)
unnamed: R71.1, U2.2 (DQ0)
unnamed: R72.1, U2.4 (DQ1)
unnamed: R73.1, U2.5 (DQ2)
unnamed: R74.1, U2.7 (DQ3)
unnamed: R75.1, U2.8 (DQ4)
unnamed: R76.1, U2.10 (DQ5)
unnamed: R77.1, U2.11 (DQ6)
unnamed: R78.1, U2.13 (DQ7)
unnamed: R79.1, U2.42 (DQ8)
unnamed: R80.1, U2.44 (DQ9)
unnamed: R81.1, U2.45 (DQ10)
unnamed: R82.1, U2.47 (DQ11)
unnamed: R83.1, U2.48 (DQ12)
unnamed: R84.1, U2.50 (DQ13)
unnamed: R85.1, U2.51 (DQ14)
unnamed: R86.1, U2.53 (DQ15)
unnamed: R67.2, U2.15 (LDQM)
unnamed: R68.2, U2.39 (UDQM)
unnamed: R62.2, U2.17 (~CAS)
unnamed: R63.2, U2.19 (~CS)
unnamed: R61.2, U2.18 (~RAS)
unnamed: R64.2, U2.16 (~WE)
PB4A: R19.1, R60.1; also elsewhere on the board
PB4B: R46.2; also elsewhere on the board
PB6A: R20.1, R59.1; also elsewhere on the board
PB6B: R47.2; also elsewhere on the board
PB9A: R45.2; also elsewhere on the board
PB11A: R44.2; also elsewhere on the board
PB11B: R43.2; also elsewhere on the board
PB13A: R42.2; also elsewhere on the board
PB13B: R40.2; also elsewhere on the board
PB15A: R41.2; also elsewhere on the board
PB15B: R39.2; also elsewhere on the board
PB18A: R38.2; also elsewhere on the board
PL14B: R18.1, R61.1; also elsewhere on the board
PL14C: R16.1, R63.1; also elsewhere on the board
PL14D: R17.1, R62.1; also elsewhere on the board
PL23D: R15.1, R64.1; also elsewhere on the board
PL32B: R10.1, R69.1; also elsewhere on the board
PL35B: R9.1, R70.1; also elsewhere on the board
PL35C: R13.1, R66.1; also elsewhere on the board
PL35D: R14.1, R65.1; also elsewhere on the board
PL38A: R31.1, R48.1; also elsewhere on the board
PL38B: R30.1, R49.1; also elsewhere on the board
PL41C: R29.1, R50.1; also elsewhere on the board
PL41D: R28.1, R51.1; also elsewhere on the board
PL44A: R27.1, R52.1; also elsewhere on the board
PL44B: R26.1, R53.1; also elsewhere on the board
PL44C: R25.1, R54.1; also elsewhere on the board
PL44D: R24.1, R55.1; also elsewhere on the board
PL47A: R23.1, R56.1; also elsewhere on the board
PL47B: R22.1, R57.1; also elsewhere on the board
PL47C: R21.1, R58.1; also elsewhere on the board
PR14A: R68.1; also elsewhere on the board
PR14B: R86.2; also elsewhere on the board
PR14C: R67.1; also elsewhere on the board
PR20A: R79.2; also elsewhere on the board
PR20B: R81.2; also elsewhere on the board
PR20C: R80.2; also elsewhere on the board
PR20D: R82.2; also elsewhere on the board
PR23A: R83.2; also elsewhere on the board
PR23B: R85.2; also elsewhere on the board
PR23C: R84.2; also elsewhere on the board
PR32C: R78.2; also elsewhere on the board
PR32D: R71.2; also elsewhere on the board
PR35A: R72.2; also elsewhere on the board
PR35B: R74.2; also elsewhere on the board
PR35C: R73.2; also elsewhere on the board
PR35D: R75.2; also elsewhere on the board
PR41A: R76.2; also elsewhere on the board
PR41B: R11.1, R77.2; also elsewhere on the board
PR41C: R12.1; also elsewhere on the board
PR41D: R32.2; also elsewhere on the board
PR44C: R33.2; also elsewhere on the board
PR47A: R34.2; also elsewhere on the board
PR47B: R37.2; also elsewhere on the board
PR47C: R35.2; also elsewhere on the board
PR47D: R36.2; also elsewhere on the board

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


Board: 2 copper layers, 100.0 x 100.0 mm, 135 parts (22 on the bottom side), 225 nets.

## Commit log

2026-04-07 add PCB and toolchain configs
    [2041411-1.step, 416131160803.step, ASE-25.000MHZ-LC-T.step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]
2026-04-10 BOM updates and readme updates , mainanence, code
    [2026-04-09T235045.xlsx, DIGI-Parts.csv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]
